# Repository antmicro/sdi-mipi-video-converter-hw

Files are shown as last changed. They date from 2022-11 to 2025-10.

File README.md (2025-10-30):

# SDI-MIPI Video Converter

Copyright (c) 2022-2025 [Antmicro](https://www.antmicro.com)


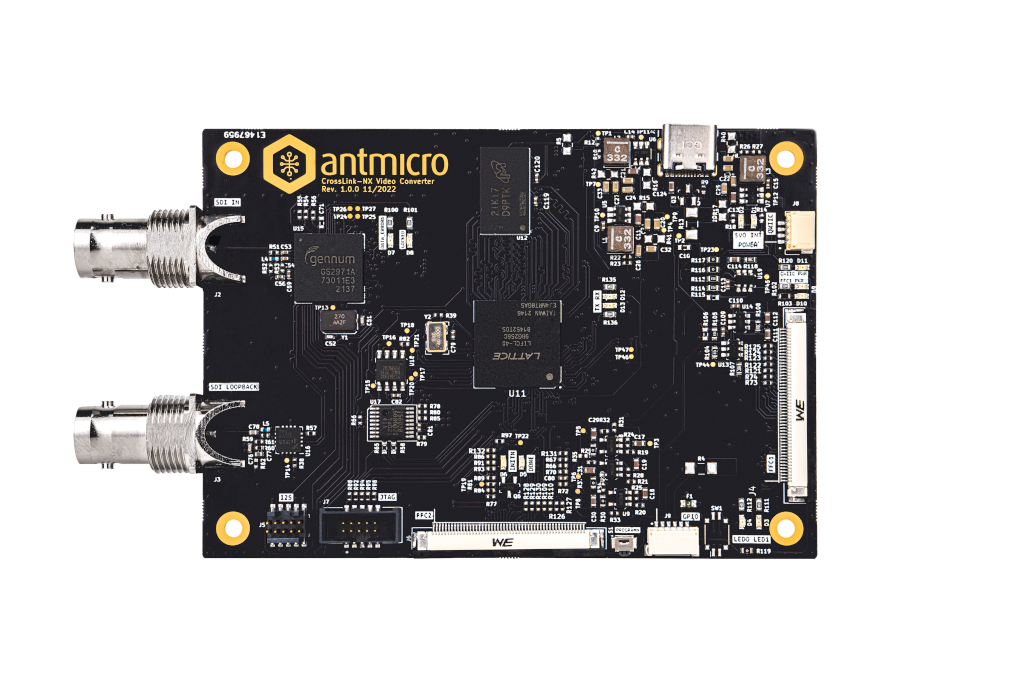
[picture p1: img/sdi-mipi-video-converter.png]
SDI-MIPI Video Converter


## Overview

This repository contains open hardware design files for a video accessory based on the [Lattice CrossLink-NX](https://www.latticesemi.com/Products/FPGAandCPLD/CrossLink-NX) FPGA which allows to connect multiple video streams from SDI or CSI inputs, process it on-board and export with CSI output.

The design files were prepared in KiCad 9.x.

## Repository structure

The main repository directory contains KiCad PCB project files, a [LICENSE](LICENSE), and a README.
The remaining files are stored in the following directories:

* `img` - contains graphics for this README

## Key Features

* LIFCL-40-9BG256C Lattice CrossLink-NX FPGA
* 3G SDI Input implemented with Semtech GS2971A deserializer 
* 3G SDI Loopback output implemented with Semtech GS2988 cable driver
* 3x4 CSI interfaces split 2/1 between two Antmicro 50-pin FFC connectors 
* 2Gbit (128Mx16) DDR3L DRAM

The board can be powered from either USB or Antmicro's 50-pin FFC connector.

Antmicro's 50-pin FFC connector is electrically compatible with several boards created by Antmicro, such as:
 
* [Jetson Nano/TX2 NX/Xavier NX Baseboard](https://github.com/antmicro/jetson-nano-baseboard)
* [OV9281 Dual Camera Board](https://github.com/antmicro/ov9281-camera-board)
* [HDMI-MIPI bridge](https://github.com/antmicro/hdmi-mipi-bridge)

## License

[Apache-2.0](LICENSE)

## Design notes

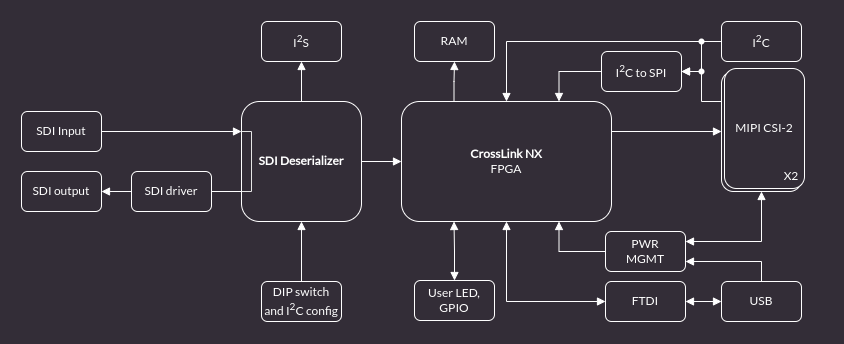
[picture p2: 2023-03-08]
doc/sdi-mipi-video-converter-diagram.png

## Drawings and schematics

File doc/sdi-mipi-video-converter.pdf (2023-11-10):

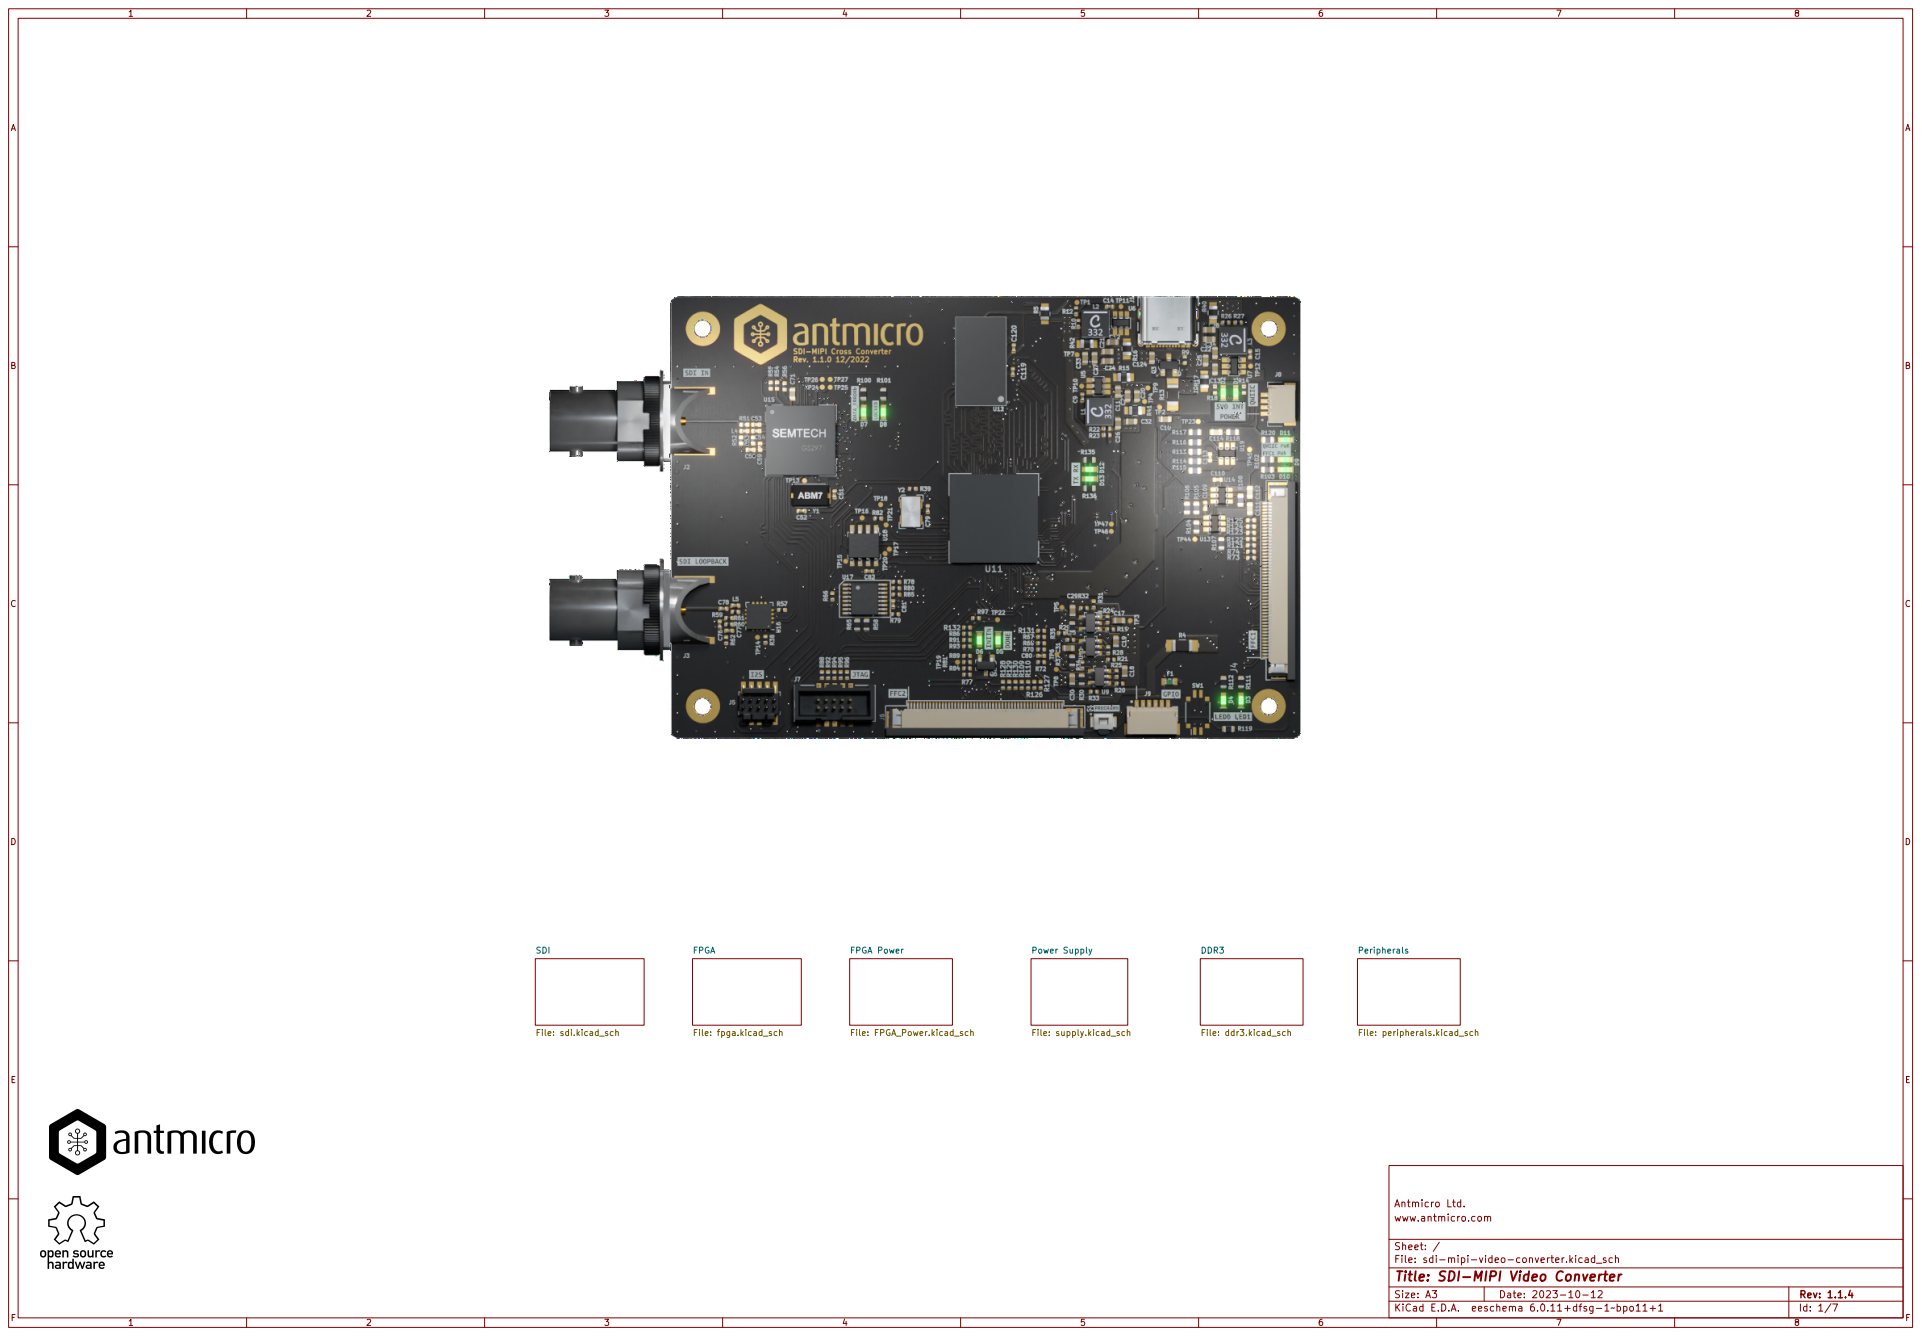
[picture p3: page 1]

Id: 1/7 Title: SDI-MIPI Video Converter File: sdi-mipi-video-converter.kicad_sch Sheet: / www.antmicro.com

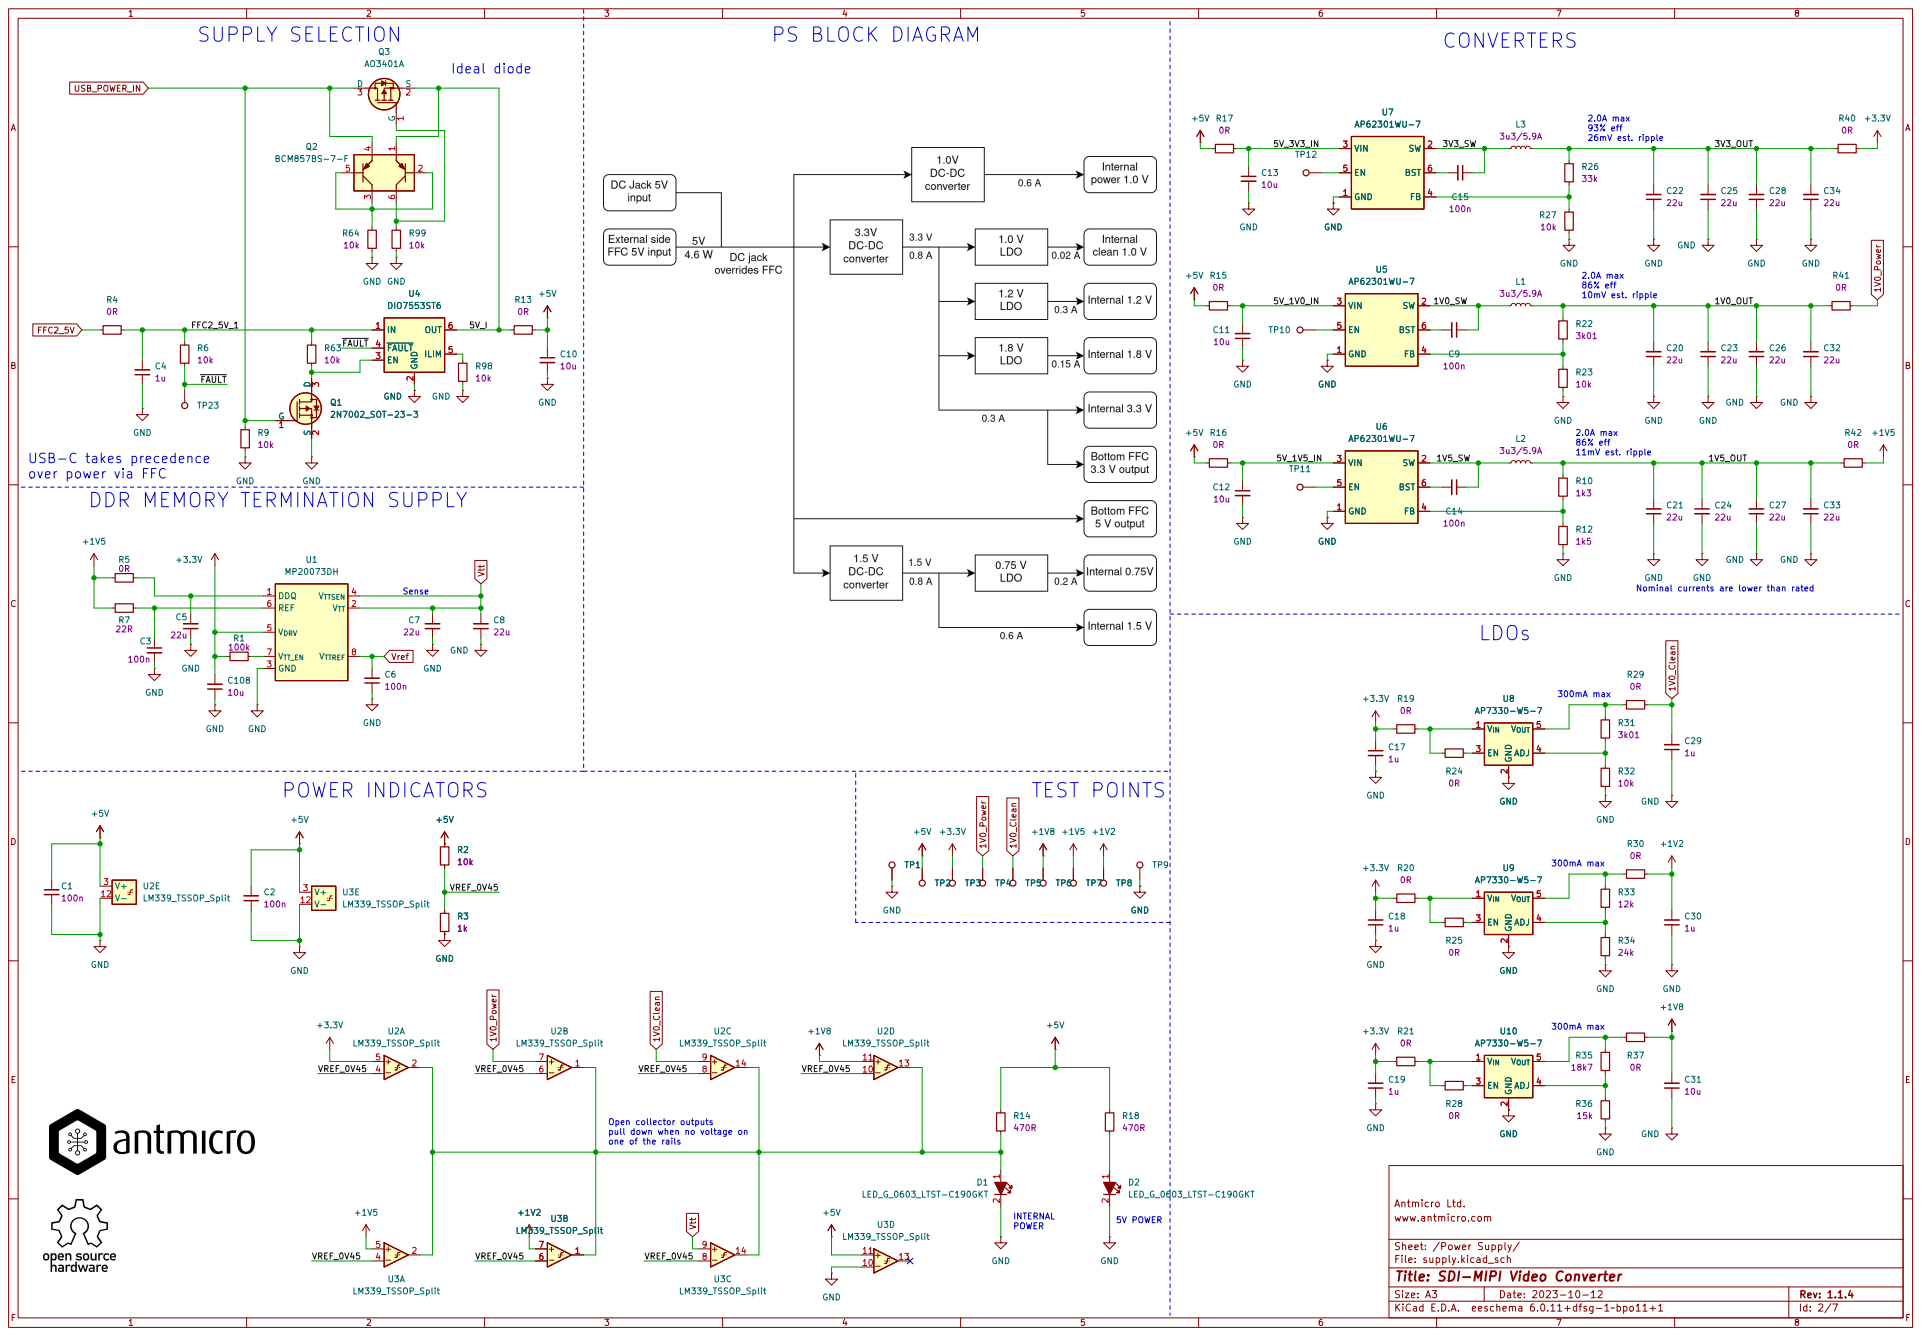
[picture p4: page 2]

2.0A max 93% eff 26mV est. ripple
+3.3V GND

2.0A max 86% eff 10mV est. ripple GND

2.0A max 86% eff 11mV est. ripple

DDR MEMORY TERMINATION SUPPLY

one of the rails

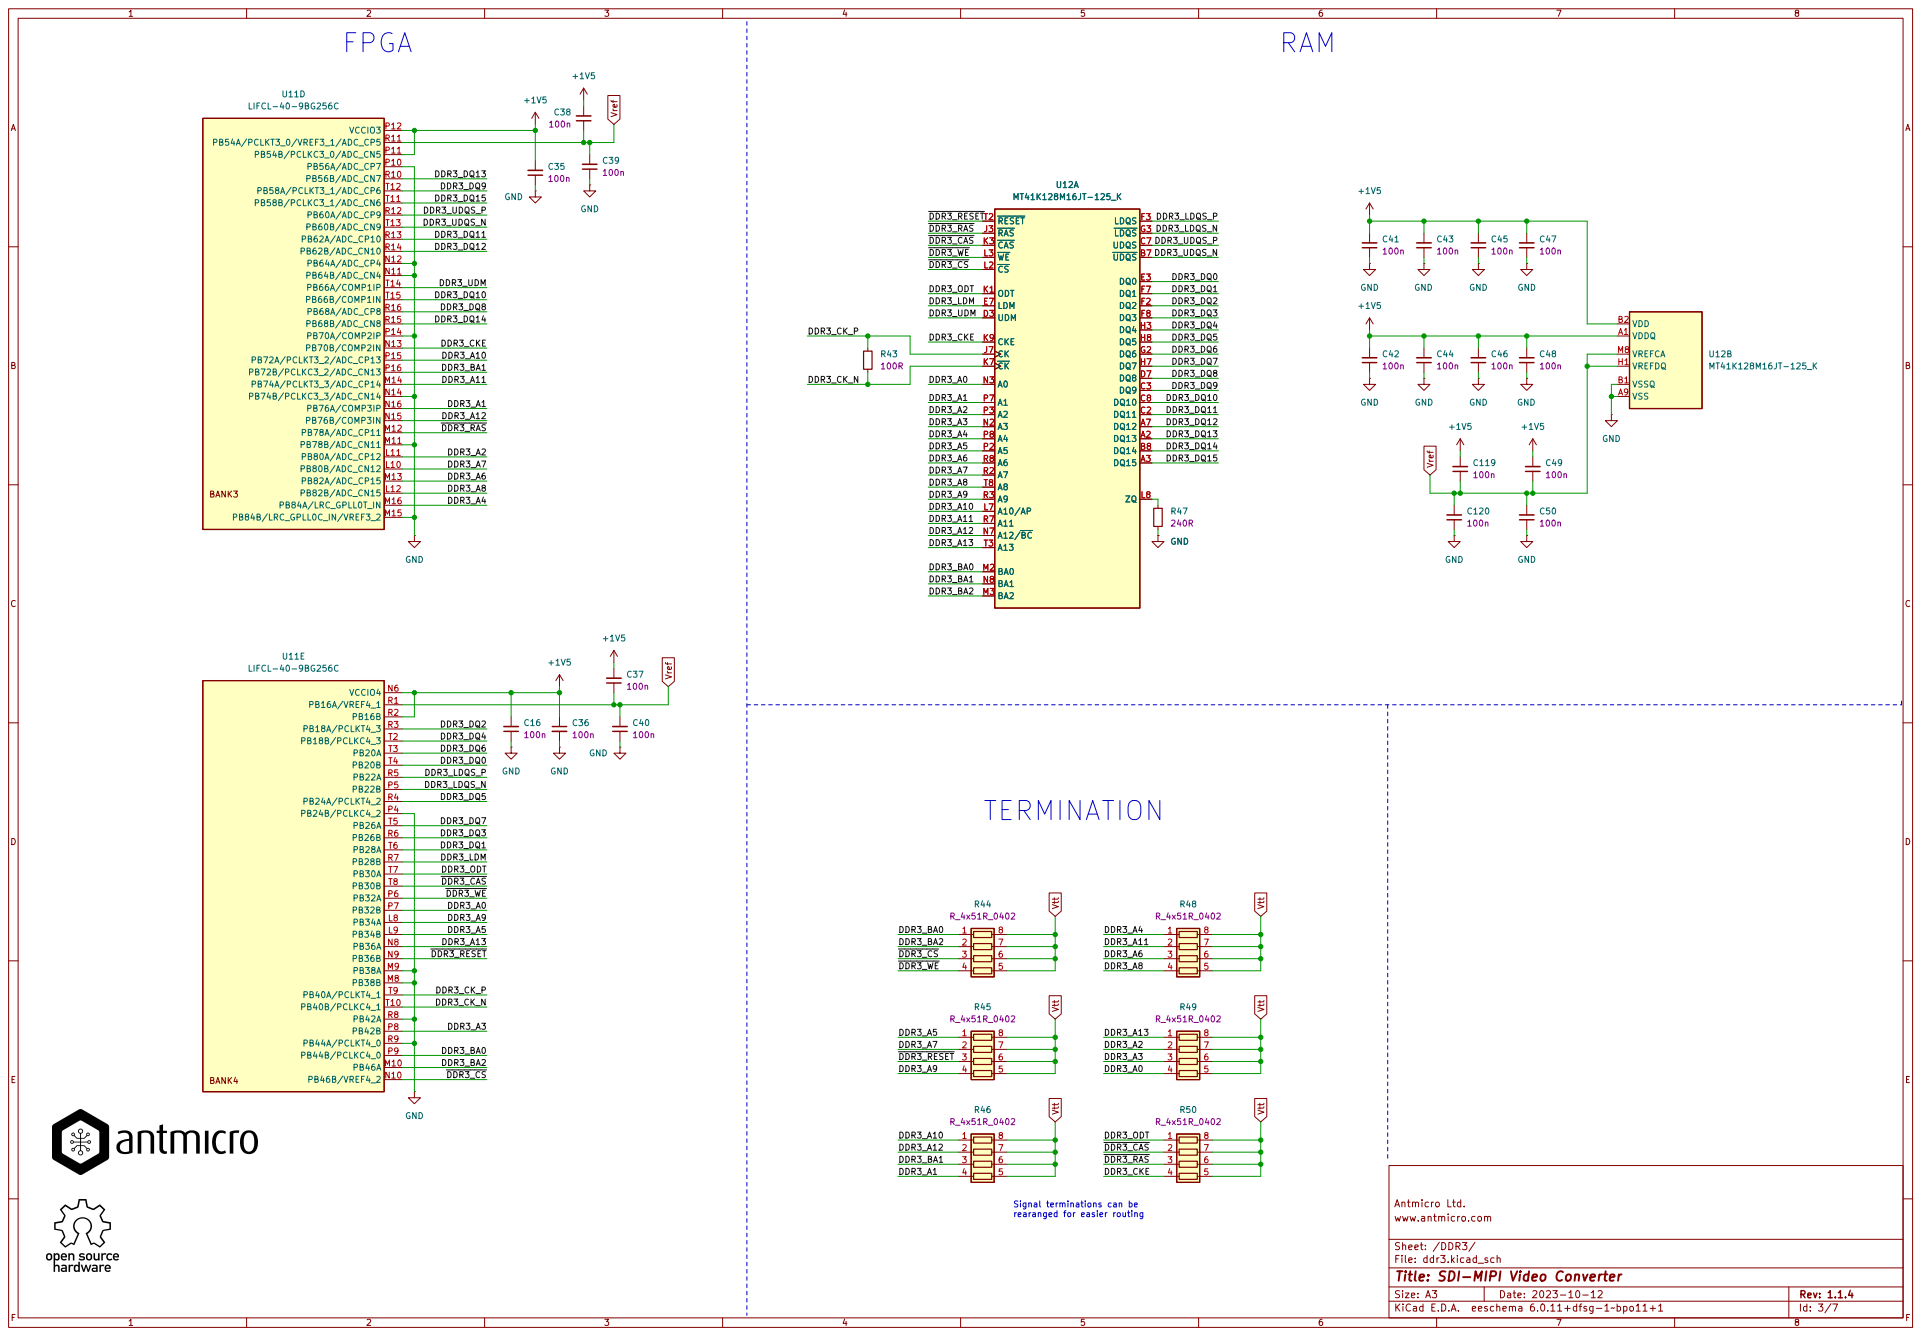
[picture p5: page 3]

Id: 3/7 Title: SDI-MIPI Video Converter File: ddr3.kicad_sch Sheet: /DDR3/ www.antmicro.com

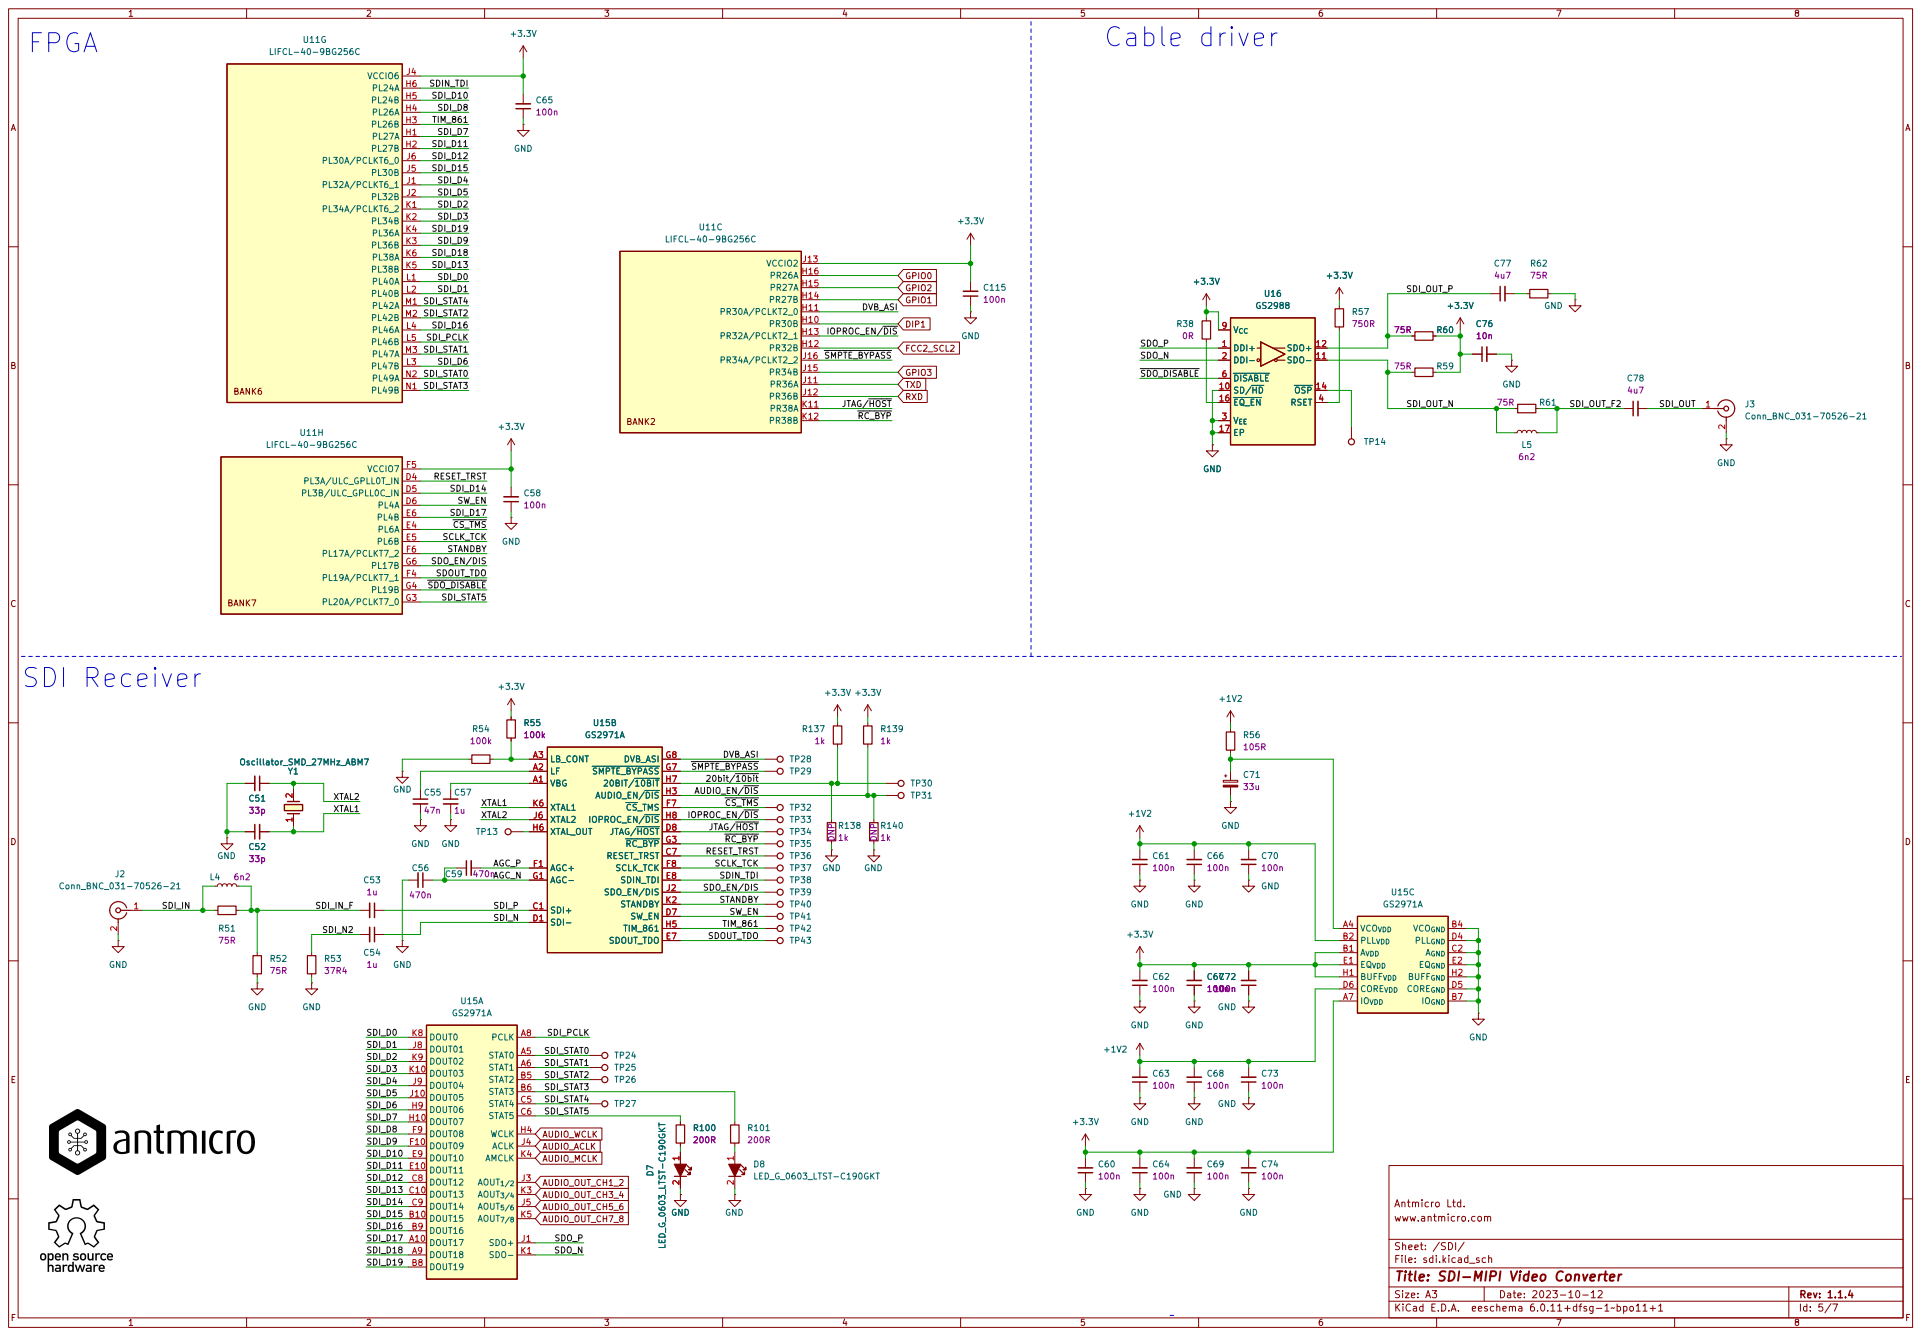
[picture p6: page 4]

Id: 5/7 Title: SDI-MIPI Video Converter File: sdi.kicad_sch Sheet: /SDI/ www.antmicro.com

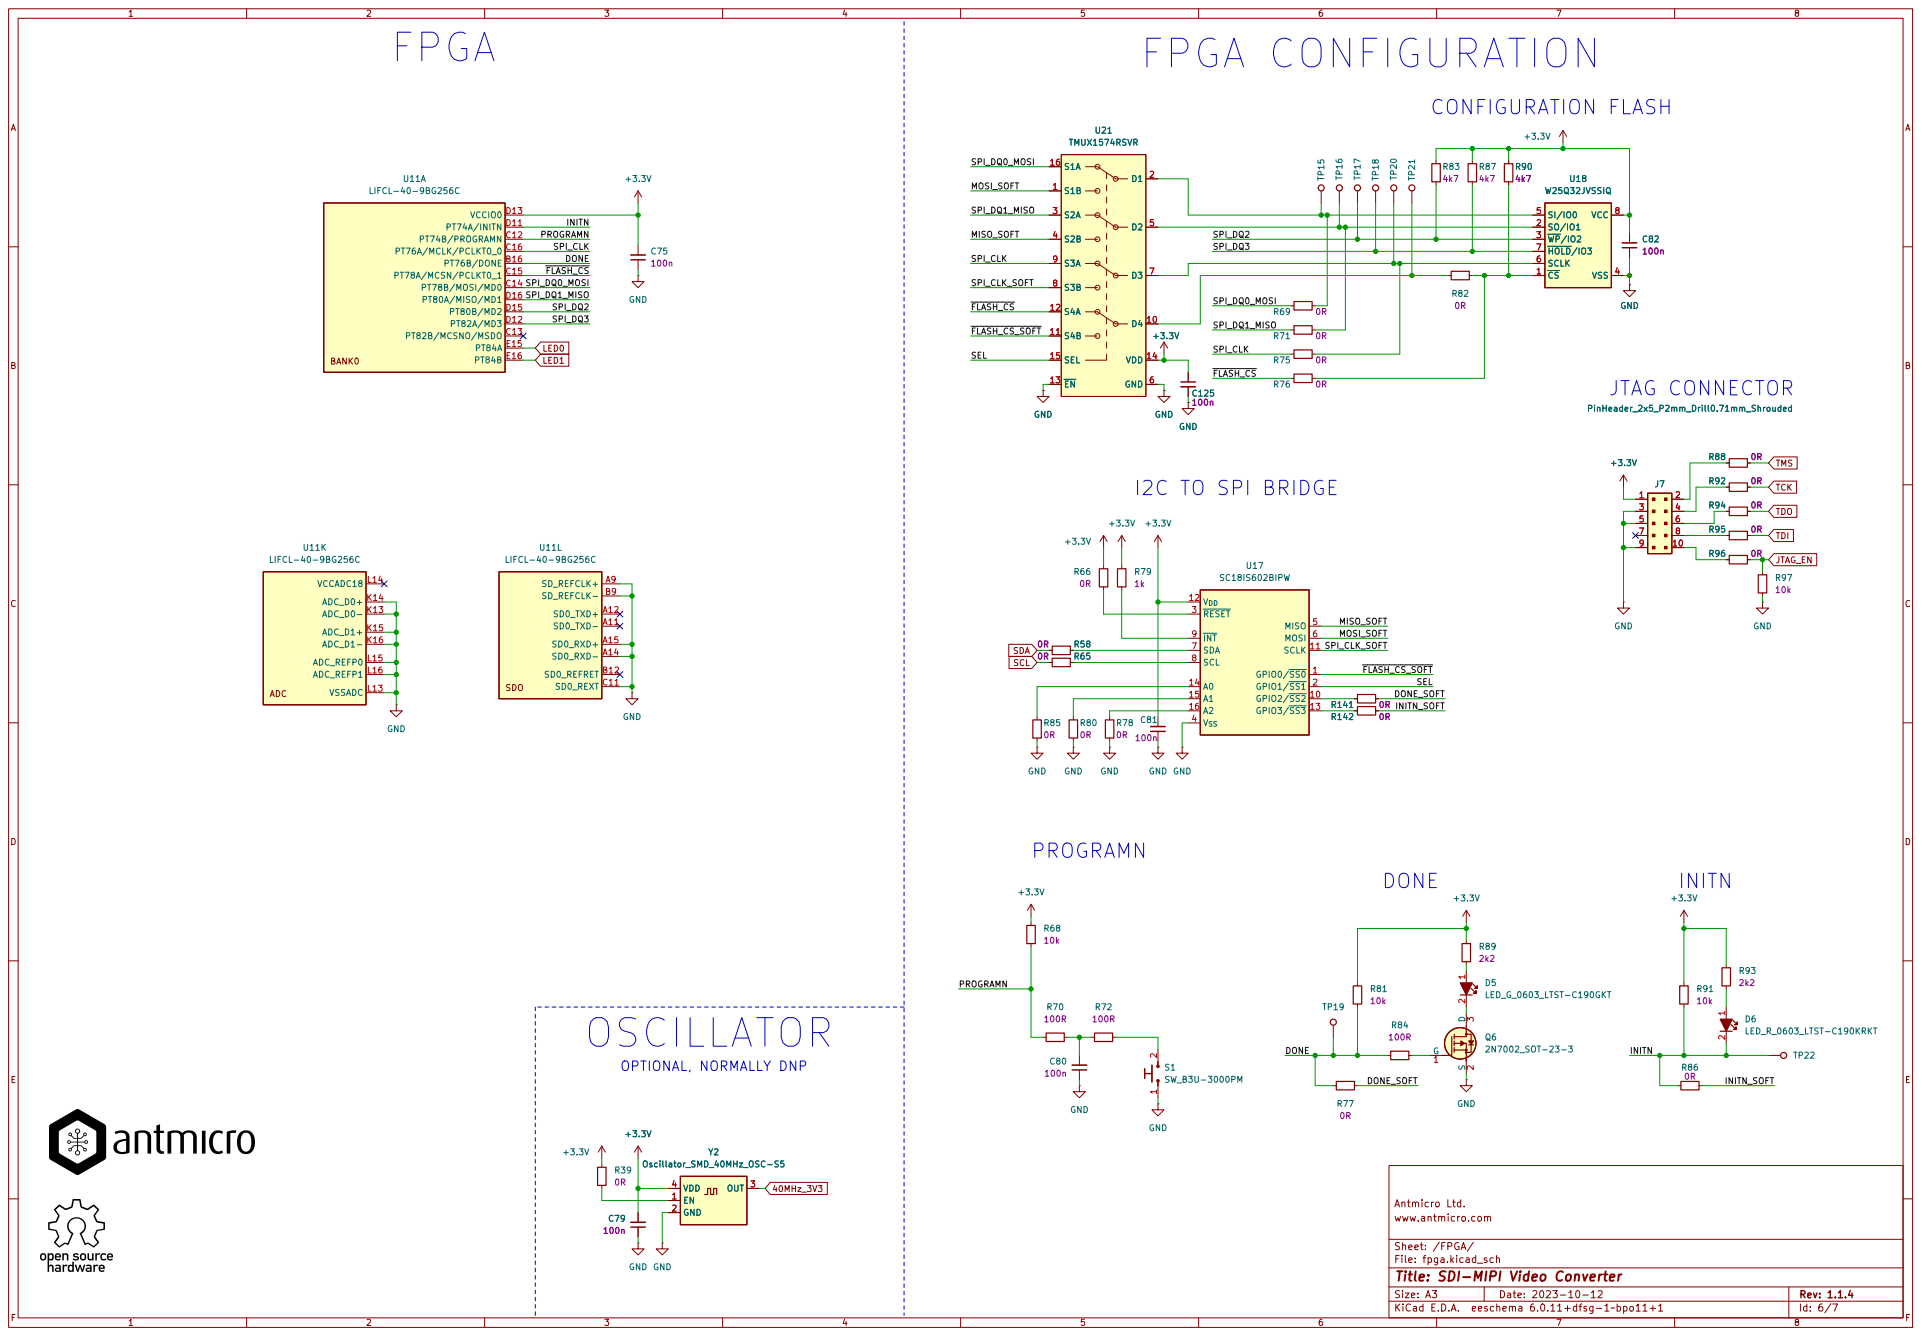
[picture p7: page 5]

Id: 6/7 Title: SDI-MIPI Video Converter File: fpga.kicad_sch Sheet: /FPGA/ www.antmicro.com

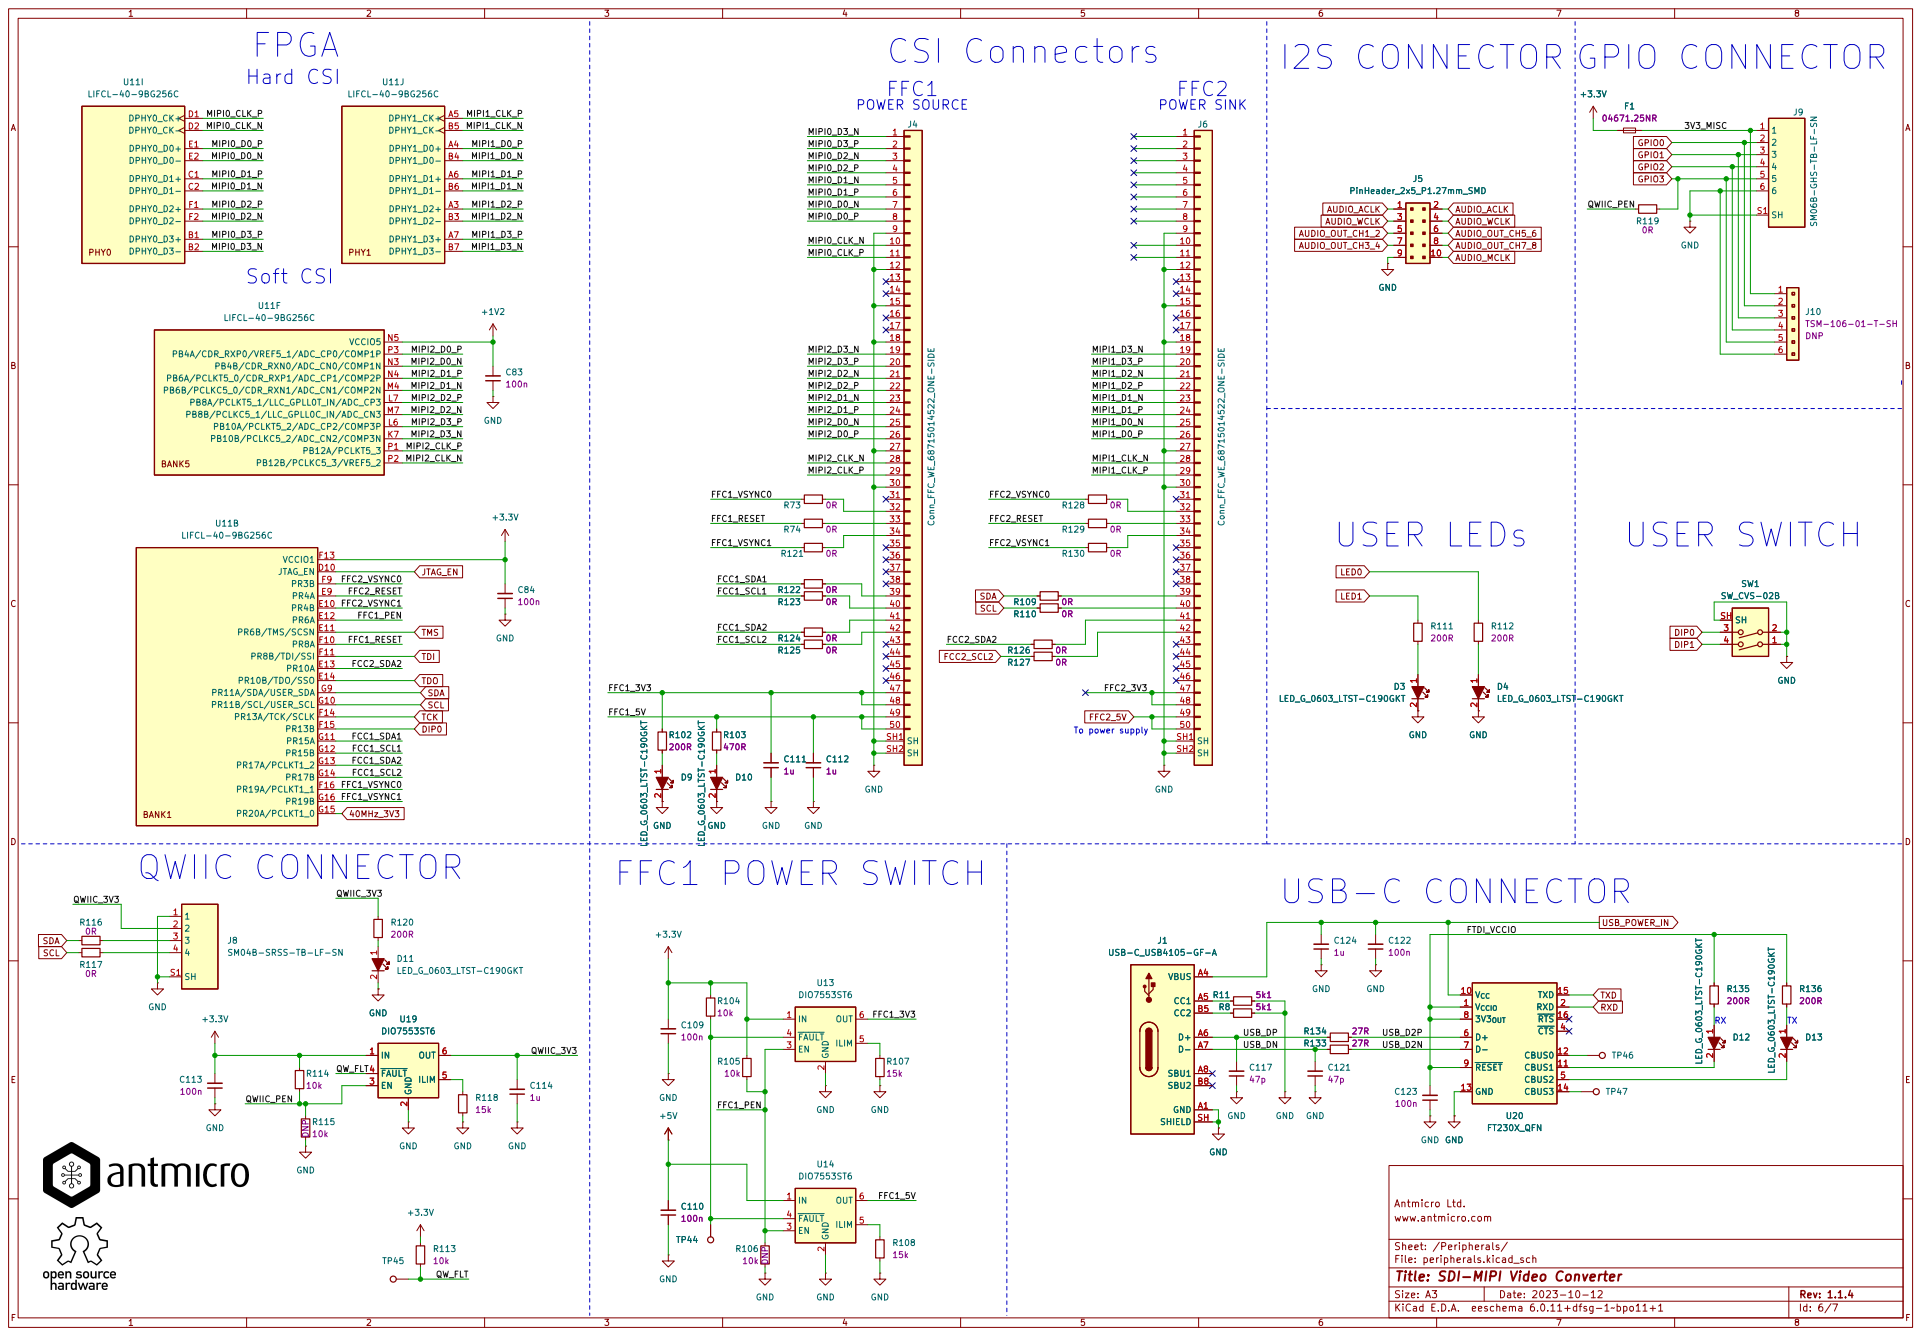
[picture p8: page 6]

J8SM04B-SRSS-TB-LF-SN

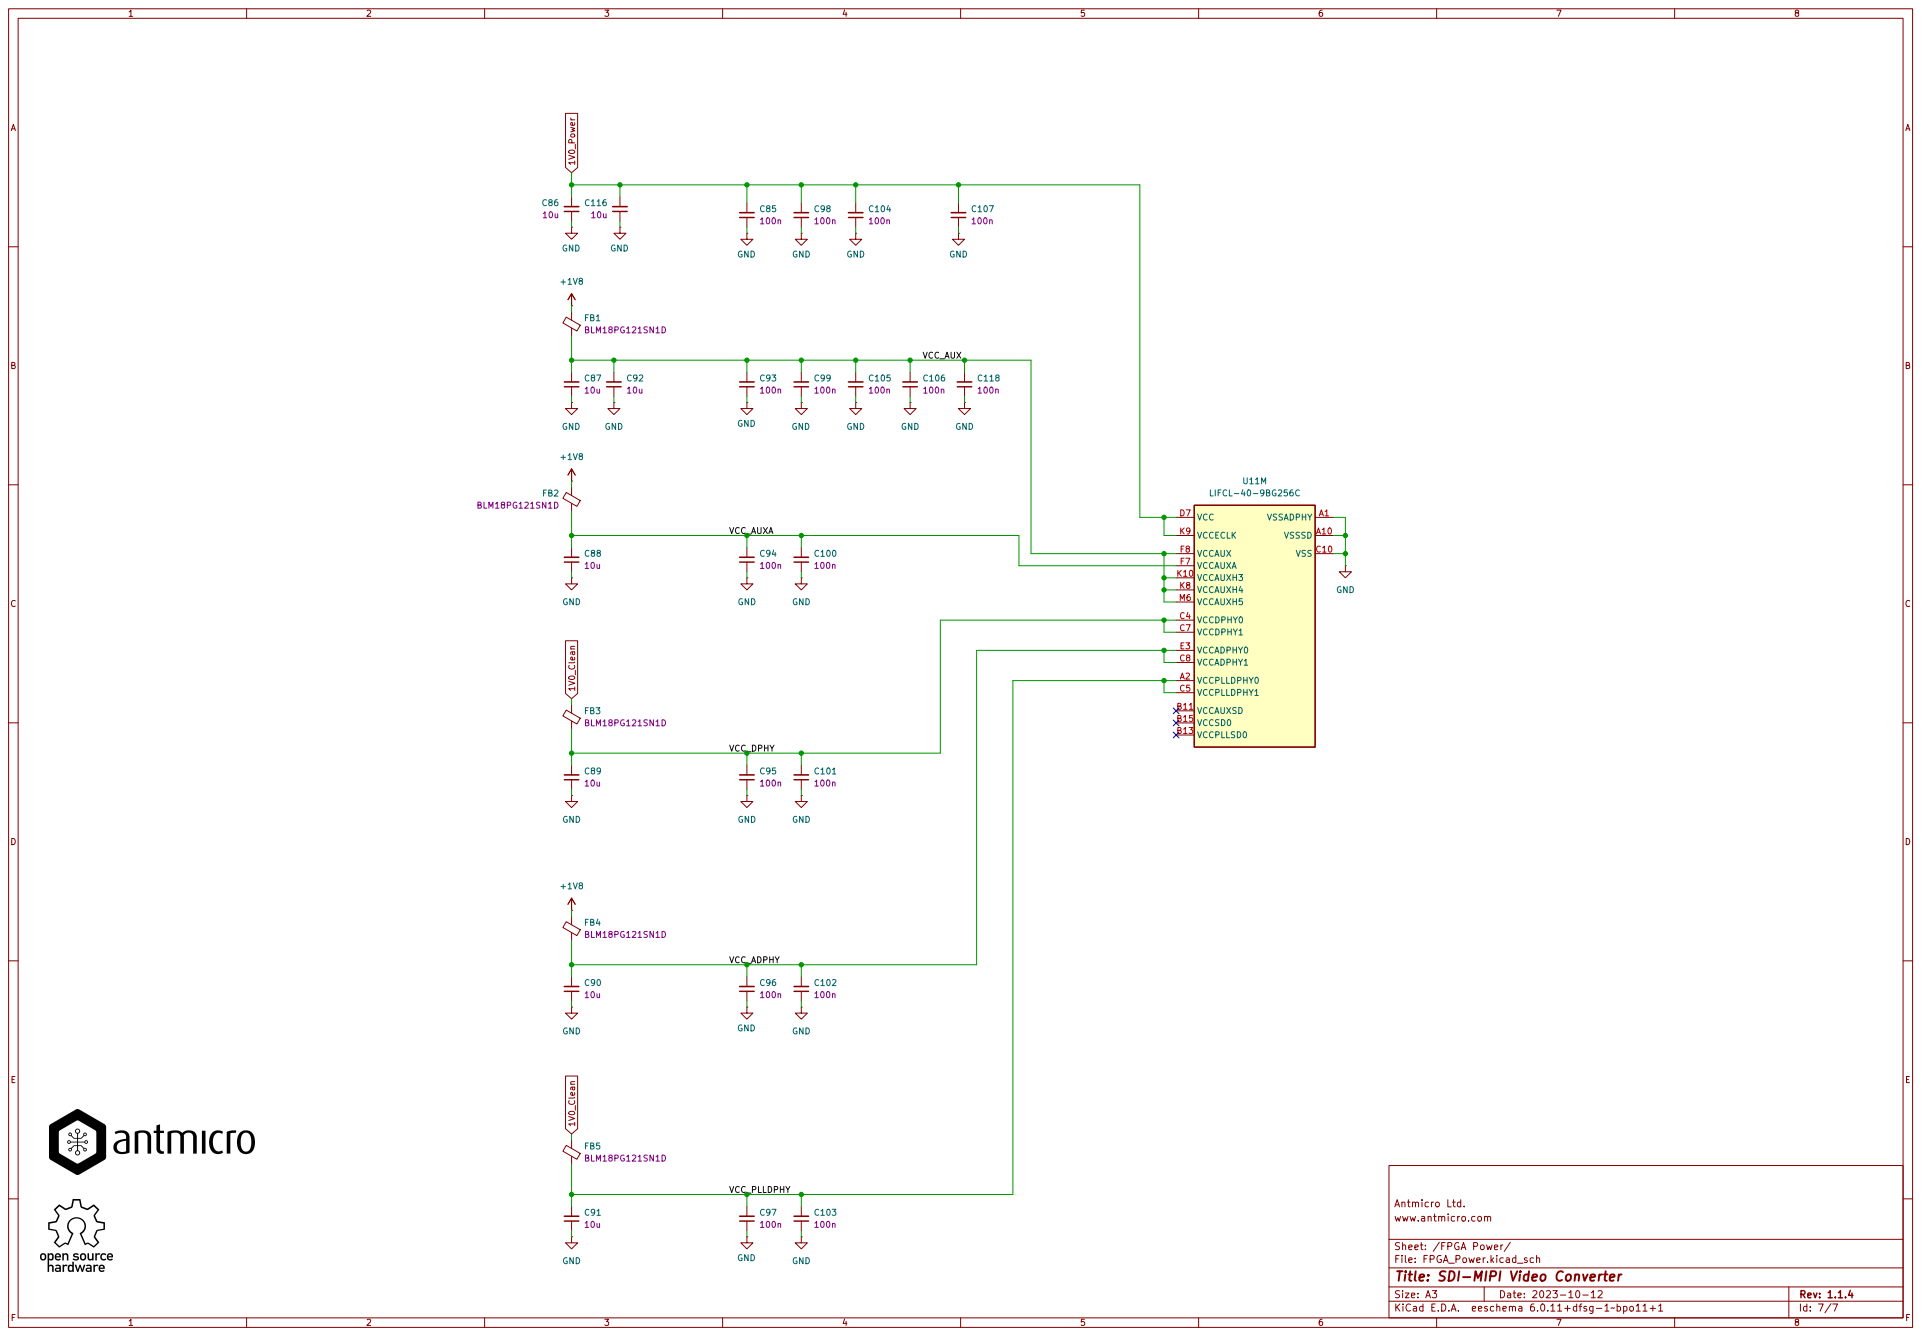
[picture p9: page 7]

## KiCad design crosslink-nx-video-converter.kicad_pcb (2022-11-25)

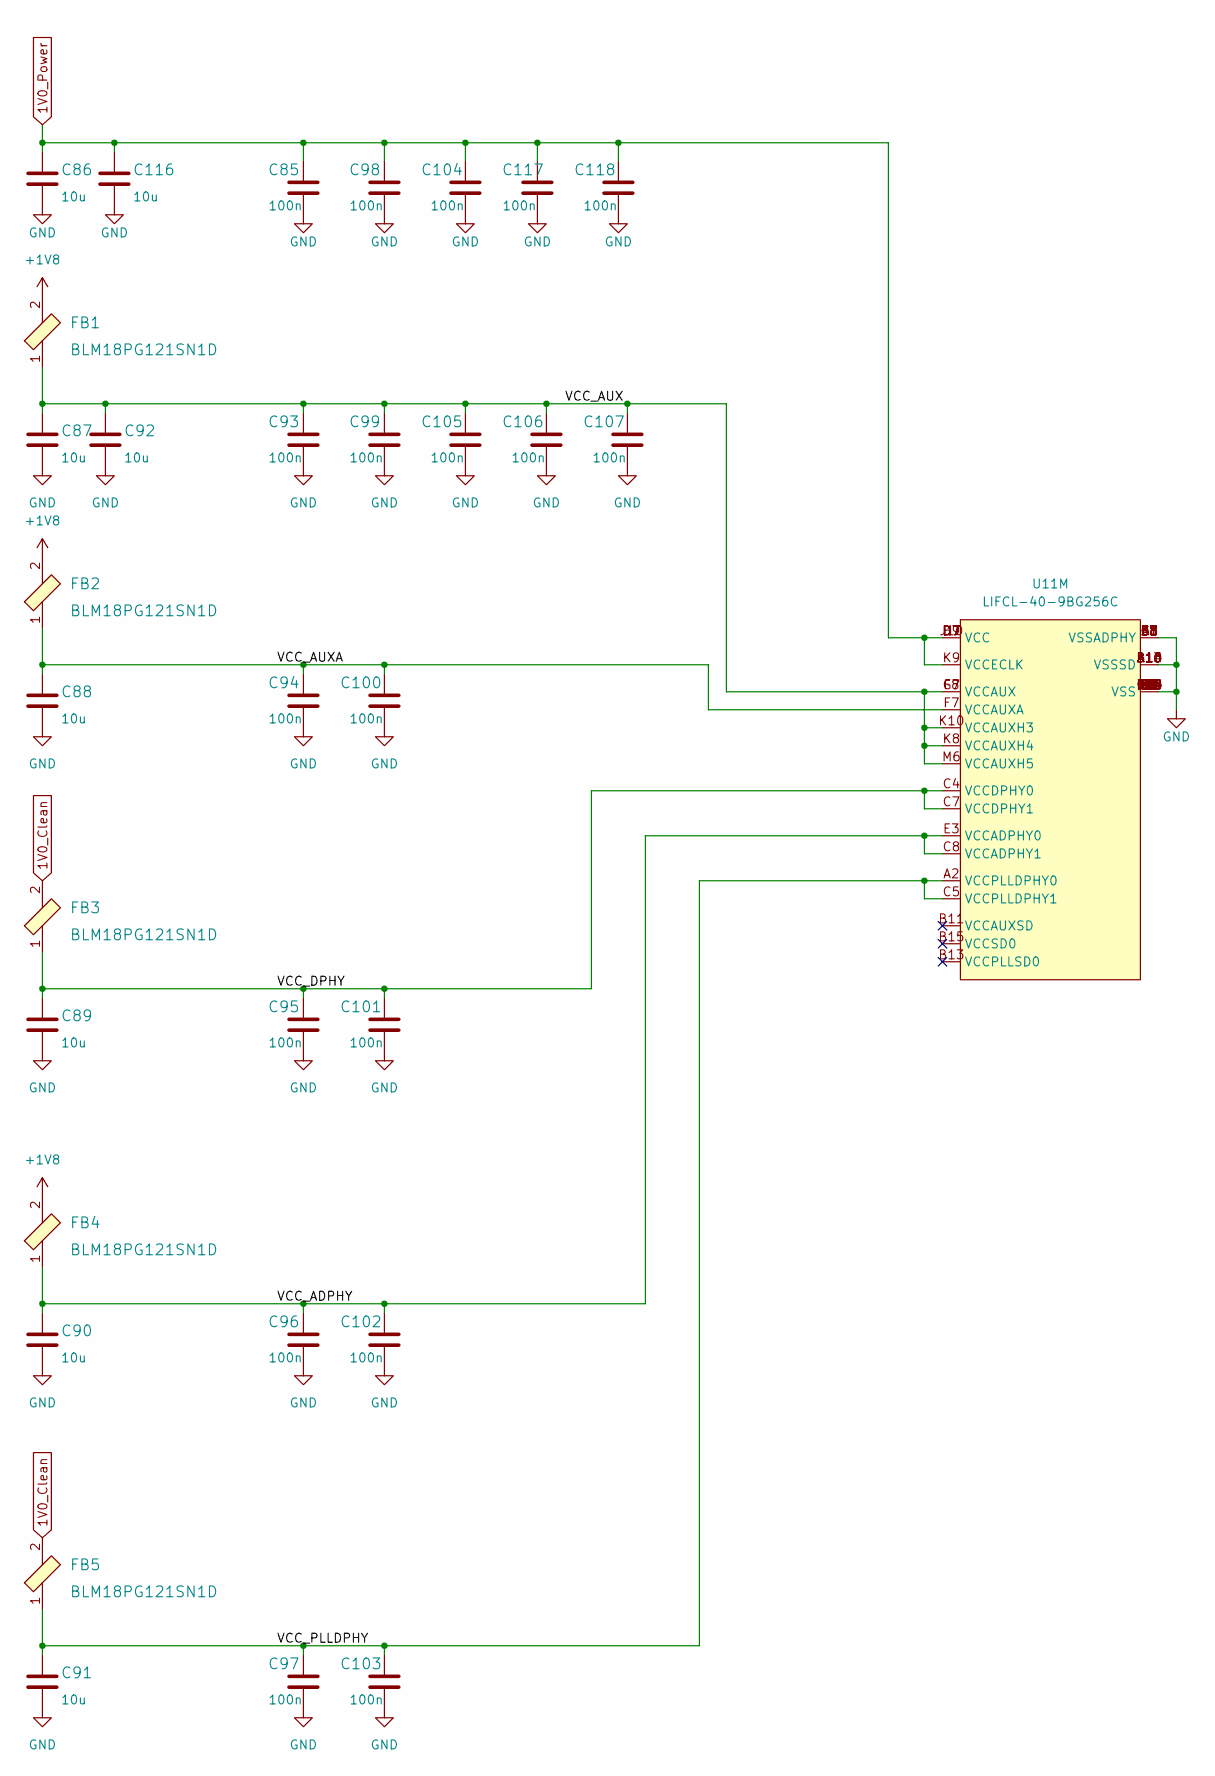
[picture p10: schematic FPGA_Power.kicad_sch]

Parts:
C85, C93, C94, C95, C96, C97, C98, C99, C100, C101, C102, C103, C104, C105, C106, C107, C117, C118: C_100n_0402; 0402-cap; MPN GRM155R61H104KE14D
C86, C87, C88, C89, C90, C91, C92, C116: C_10u_0603; 0603-cap; MPN GRM188R61A106KE69D
FB1, FB2, FB3, FB4, FB5: BLM18PG121SN1D; 0603-res; MPN BLM18PG121SN1D
U11: LIFCL-40-9BG256C; BGA-256_16x16_14.0x14.0mm; MPN LIFCL-40-9BG256C

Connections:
/FPGA Power/VCC_ADPHY: C90.1, C96.1, C102.1, FB4.1, U11.C8 (VCCADPHY1), U11.E3 (VCCADPHY0)
/FPGA Power/VCC_AUX: C87.1, C92.1, C93.1, C99.1, C105.1, C106.1, C107.1, FB1.1, U11.F8 (VCCAUX), U11.G7 (VCCAUX), U11.K8 (VCCAUXH4), U11.K10 (VCCAUXH3), U11.M6 (VCCAUXH5)
/FPGA Power/VCC_AUXA: C88.1, C94.1, C100.1, FB2.1, U11.F7 (VCCAUXA)
/FPGA Power/VCC_DPHY: C89.1, C95.1, C101.1, FB3.1, U11.C4 (VCCDPHY0), U11.C7 (VCCDPHY1)
/FPGA Power/VCC_PLLDPHY: C91.1, C97.1, C103.1, FB5.1, U11.A2 (VCCPLLDPHY0), U11.C5 (VCCPLLDPHY1)

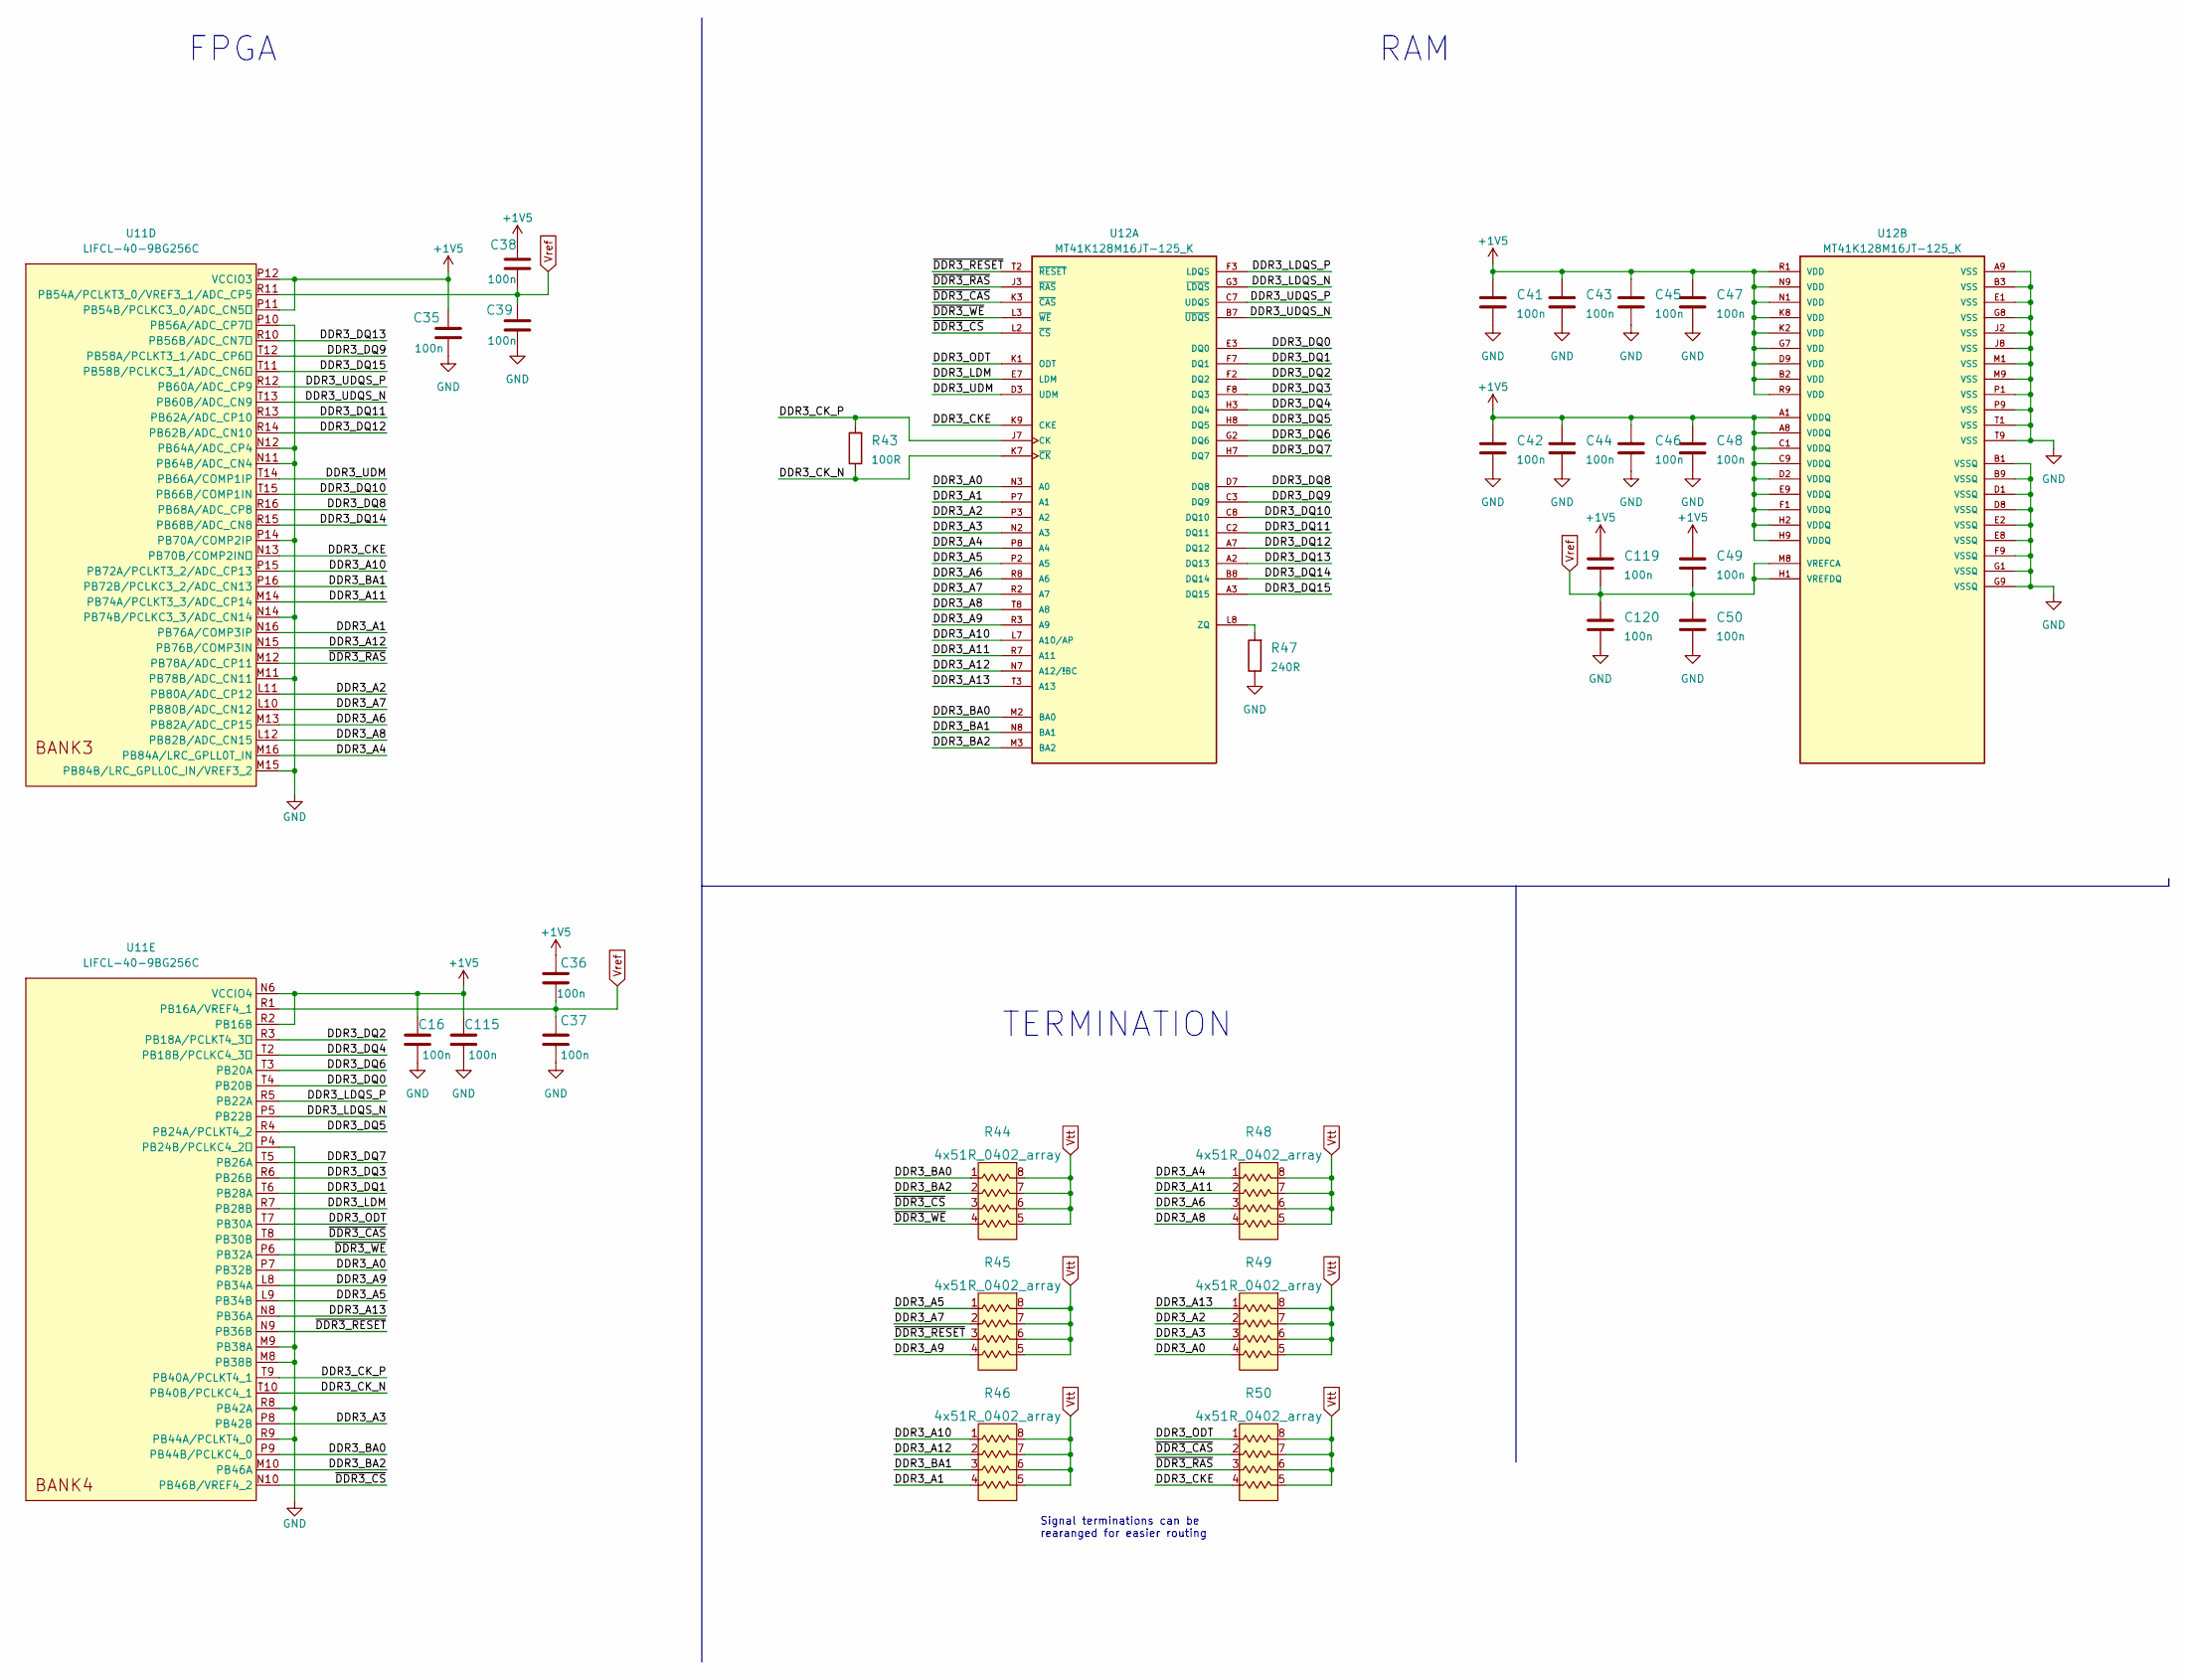
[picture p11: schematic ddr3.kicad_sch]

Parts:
C16, C35, C36, C37, C38, C39, C41, C42, C43, C44, C45, C46, C47, C48, C49, C50, C115, C119, C120: C_100n_0402; 0402-cap; MPN GRM155R61H104KE14D
R43: R_100R_0201; 0201-res; MPN CR0201AFW-1000GAS
R44, R45, R46, R48, R49, R50: 4x51R_0402_array; R_Array_4x0402; MPN EXB28V510JX
R47: R_240R_1%_0402; 0402-res; MPN RC0402FR-13240RL
U11: LIFCL-40-9BG256C; BGA-256_16x16_14.0x14.0mm; MPN LIFCL-40-9BG256C
U12: MT41K128M16JT-125_K; BGA80P96C6X16_800X1400X110; MPN MT41K128M16JT-125:K

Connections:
+1V5: C16.1, C35.1, C36.1, C38.1, C41.1, C42.1, C43.1, C44.1, C45.1, C46.1, C47.1, C48.1, C49.1, C115.1, C119.1, U11.N6 (VCCIO4), U11.P11 (PB54B/PCLKC3_0/ADC_CN5), U11.P12 (VCCIO3), U11.R2 (PB16B), U12.A1 (VDDQ), U12.A8 (VDDQ), U12.B2 (VDD), U12.C1 (VDDQ), U12.C9 (VDDQ), U12.D2 (VDDQ), U12.D9 (VDD), U12.E9 (VDDQ), U12.F1 (VDDQ), U12.G7 (VDD), U12.H2 (VDDQ), U12.H9 (VDDQ), U12.K2 (VDD), U12.K8 (VDD), U12.N1 (VDD), U12.N9 (VDD), U12.R1 (VDD), U12.R9 (VDD); also elsewhere on the board
/DDR3/DDR3_A0: R49.4, U11.P7 (PB32B), U12.N3 (A0)
/DDR3/DDR3_A1: R46.4, U11.N16 (PB76A/COMP3IP), U12.P7 (A1)
/DDR3/DDR3_A2: R49.2, U11.L11 (PB80A/ADC_CP12), U12.P3 (A2)
/DDR3/DDR3_A3: R49.3, U11.P8 (PB42B), U12.N2 (A3)
/DDR3/DDR3_A4: R48.1, U11.M16 (PB84A/LRC_GPLL0T_IN), U12.P8 (A4)
/DDR3/DDR3_A5: R45.1, U11.L9 (PB34B), U12.P2 (A5)
/DDR3/DDR3_A6: R48.3, U11.M13 (PB82A/ADC_CP15), U12.R8 (A6)
/DDR3/DDR3_A7: R45.2, U11.L10 (PB80B/ADC_CN12), U12.R2 (A7)
/DDR3/DDR3_A8: R48.4, U11.L12 (PB82B/ADC_CN15), U12.T8 (A8)
/DDR3/DDR3_A9: R45.4, U11.L8 (PB34A), U12.R3 (A9)
/DDR3/DDR3_A10: R46.1, U11.P15 (PB72A/PCLKT3_2/ADC_CP13), U12.L7 (A10/AP)
/DDR3/DDR3_A11: R48.2, U11.M14 (PB74A/PCLKT3_3/ADC_CP14), U12.R7 (A11)
/DDR3/DDR3_A12: R46.2, U11.N15 (PB76B/COMP3IN), U12.N7 (A12/!BC)
/DDR3/DDR3_A13: R49.1, U11.N8 (PB36A), U12.T3 (A13)
/DDR3/DDR3_BA0: R44.1, U11.P9 (PB44B/PCLKC4_0), U12.M2 (BA0)
/DDR3/DDR3_BA1: R46.3, U11.P16 (PB72B/PCLKC3_2/ADC_CN13), U12.N8 (BA1)
/DDR3/DDR3_BA2: R44.2, U11.M10 (PB46A), U12.M3 (BA2)
/DDR3/DDR3_CKE: R50.4, U11.N13 (PB70B/COMP2IN), U12.K9 (CKE)
/DDR3/DDR3_CK_N: R43.1, U11.T10 (PB40B/PCLKC4_1), U12.K7 (~CK)
/DDR3/DDR3_CK_P: R43.2, U11.T9 (PB40A/PCLKT4_1), U12.J7 (CK)
/DDR3/DDR3_DQ0: U11.T4 (PB20B), U12.E3 (DQ0)
/DDR3/DDR3_DQ1: U11.T6 (PB28A), U12.F7 (DQ1)
/DDR3/DDR3_DQ2: U11.R3 (PB18A/PCLKT4_3), U12.F2 (DQ2)
/DDR3/DDR3_DQ3: U11.R6 (PB26B), U12.F8 (DQ3)
/DDR3/DDR3_DQ4: U11.T2 (PB18B/PCLKC4_3), U12.H3 (DQ4)
/DDR3/DDR3_DQ5: U11.R4 (PB24A/PCLKT4_2), U12.H8 (DQ5)
/DDR3/DDR3_DQ6: U11.T3 (PB20A), U12.G2 (DQ6)
/DDR3/DDR3_DQ7: U11.T5 (PB26A), U12.H7 (DQ7)
/DDR3/DDR3_DQ8: U11.R16 (PB68A/ADC_CP8), U12.D7 (DQ8)
/DDR3/DDR3_DQ9: U11.T12 (PB58A/PCLKT3_1/ADC_CP6), U12.C3 (DQ9)
/DDR3/DDR3_DQ10: U11.T15 (PB66B/COMP1IN), U12.C8 (DQ10)
/DDR3/DDR3_DQ11: U11.R13 (PB62A/ADC_CP10), U12.C2 (DQ11)
/DDR3/DDR3_DQ12: U11.R14 (PB62B/ADC_CN10), U12.A7 (DQ12)
/DDR3/DDR3_DQ13: U11.R10 (PB56B/ADC_CN7), U12.A2 (DQ13)
/DDR3/DDR3_DQ14: U11.R15 (PB68B/ADC_CN8), U12.B8 (DQ14)
/DDR3/DDR3_DQ15: U11.T11 (PB58B/PCLKC3_1/ADC_CN6), U12.A3 (DQ15)
/DDR3/DDR3_LDM: U11.R7 (PB28B), U12.E7 (LDM)
/DDR3/DDR3_LDQS_N: U11.P5 (PB22B), U12.G3 (~LDQS)
/DDR3/DDR3_LDQS_P: U11.R5 (PB22A), U12.F3 (LDQS)
/DDR3/DDR3_ODT: R50.1, U11.T7 (PB30A), U12.K1 (ODT)
/DDR3/DDR3_UDM: U11.T14 (PB66A/COMP1IP), U12.D3 (UDM)
/DDR3/DDR3_UDQS_N: U11.T13 (PB60B/ADC_CN9), U12.B7 (~UDQS)
/DDR3/DDR3_UDQS_P: U11.R12 (PB60A/ADC_CP9), U12.C7 (UDQS)
/DDR3/~DDR3_CAS: R50.2, U11.T8 (PB30B), U12.K3 (~CAS)
/DDR3/~DDR3_CS: R44.3, U11.N10 (PB46B/VREF4_2), U12.L2 (~CS)
/DDR3/~DDR3_RAS: R50.3, U11.M12 (PB78A/ADC_CP11), U12.J3 (~RAS)
/DDR3/~DDR3_RESET: R45.3, U11.N9 (PB36B), U12.T2 (~RESET)
/DDR3/~DDR3_WE: R44.4, U11.P6 (PB32A), U12.L3 (~WE)
unnamed: R47.2, U12.L8 (ZQ)
Vref: C36.2, C37.1, C38.2, C39.1, C49.2, C50.1, C119.2, C120.1, U11.R1 (PB16A/VREF4_1), U11.R11 (PB54A/PCLKT3_0/VREF3_1/ADC_CP5), U12.H1 (VREFDQ), U12.M8 (VREFCA); also elsewhere on the board
Vtt: R44.5, R44.6, R44.7, R44.8, R45.5, R45.6, R45.7, R45.8, R46.5, R46.6, R46.7, R46.8, R48.5, R48.6, R48.7, R48.8, R49.5, R49.6, R49.7, R49.8, R50.5, R50.6, R50.7, R50.8; also elsewhere on the board

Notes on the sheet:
FPGA
TERMINATION
RAM
Signal terminations can be rearanged for easier routing

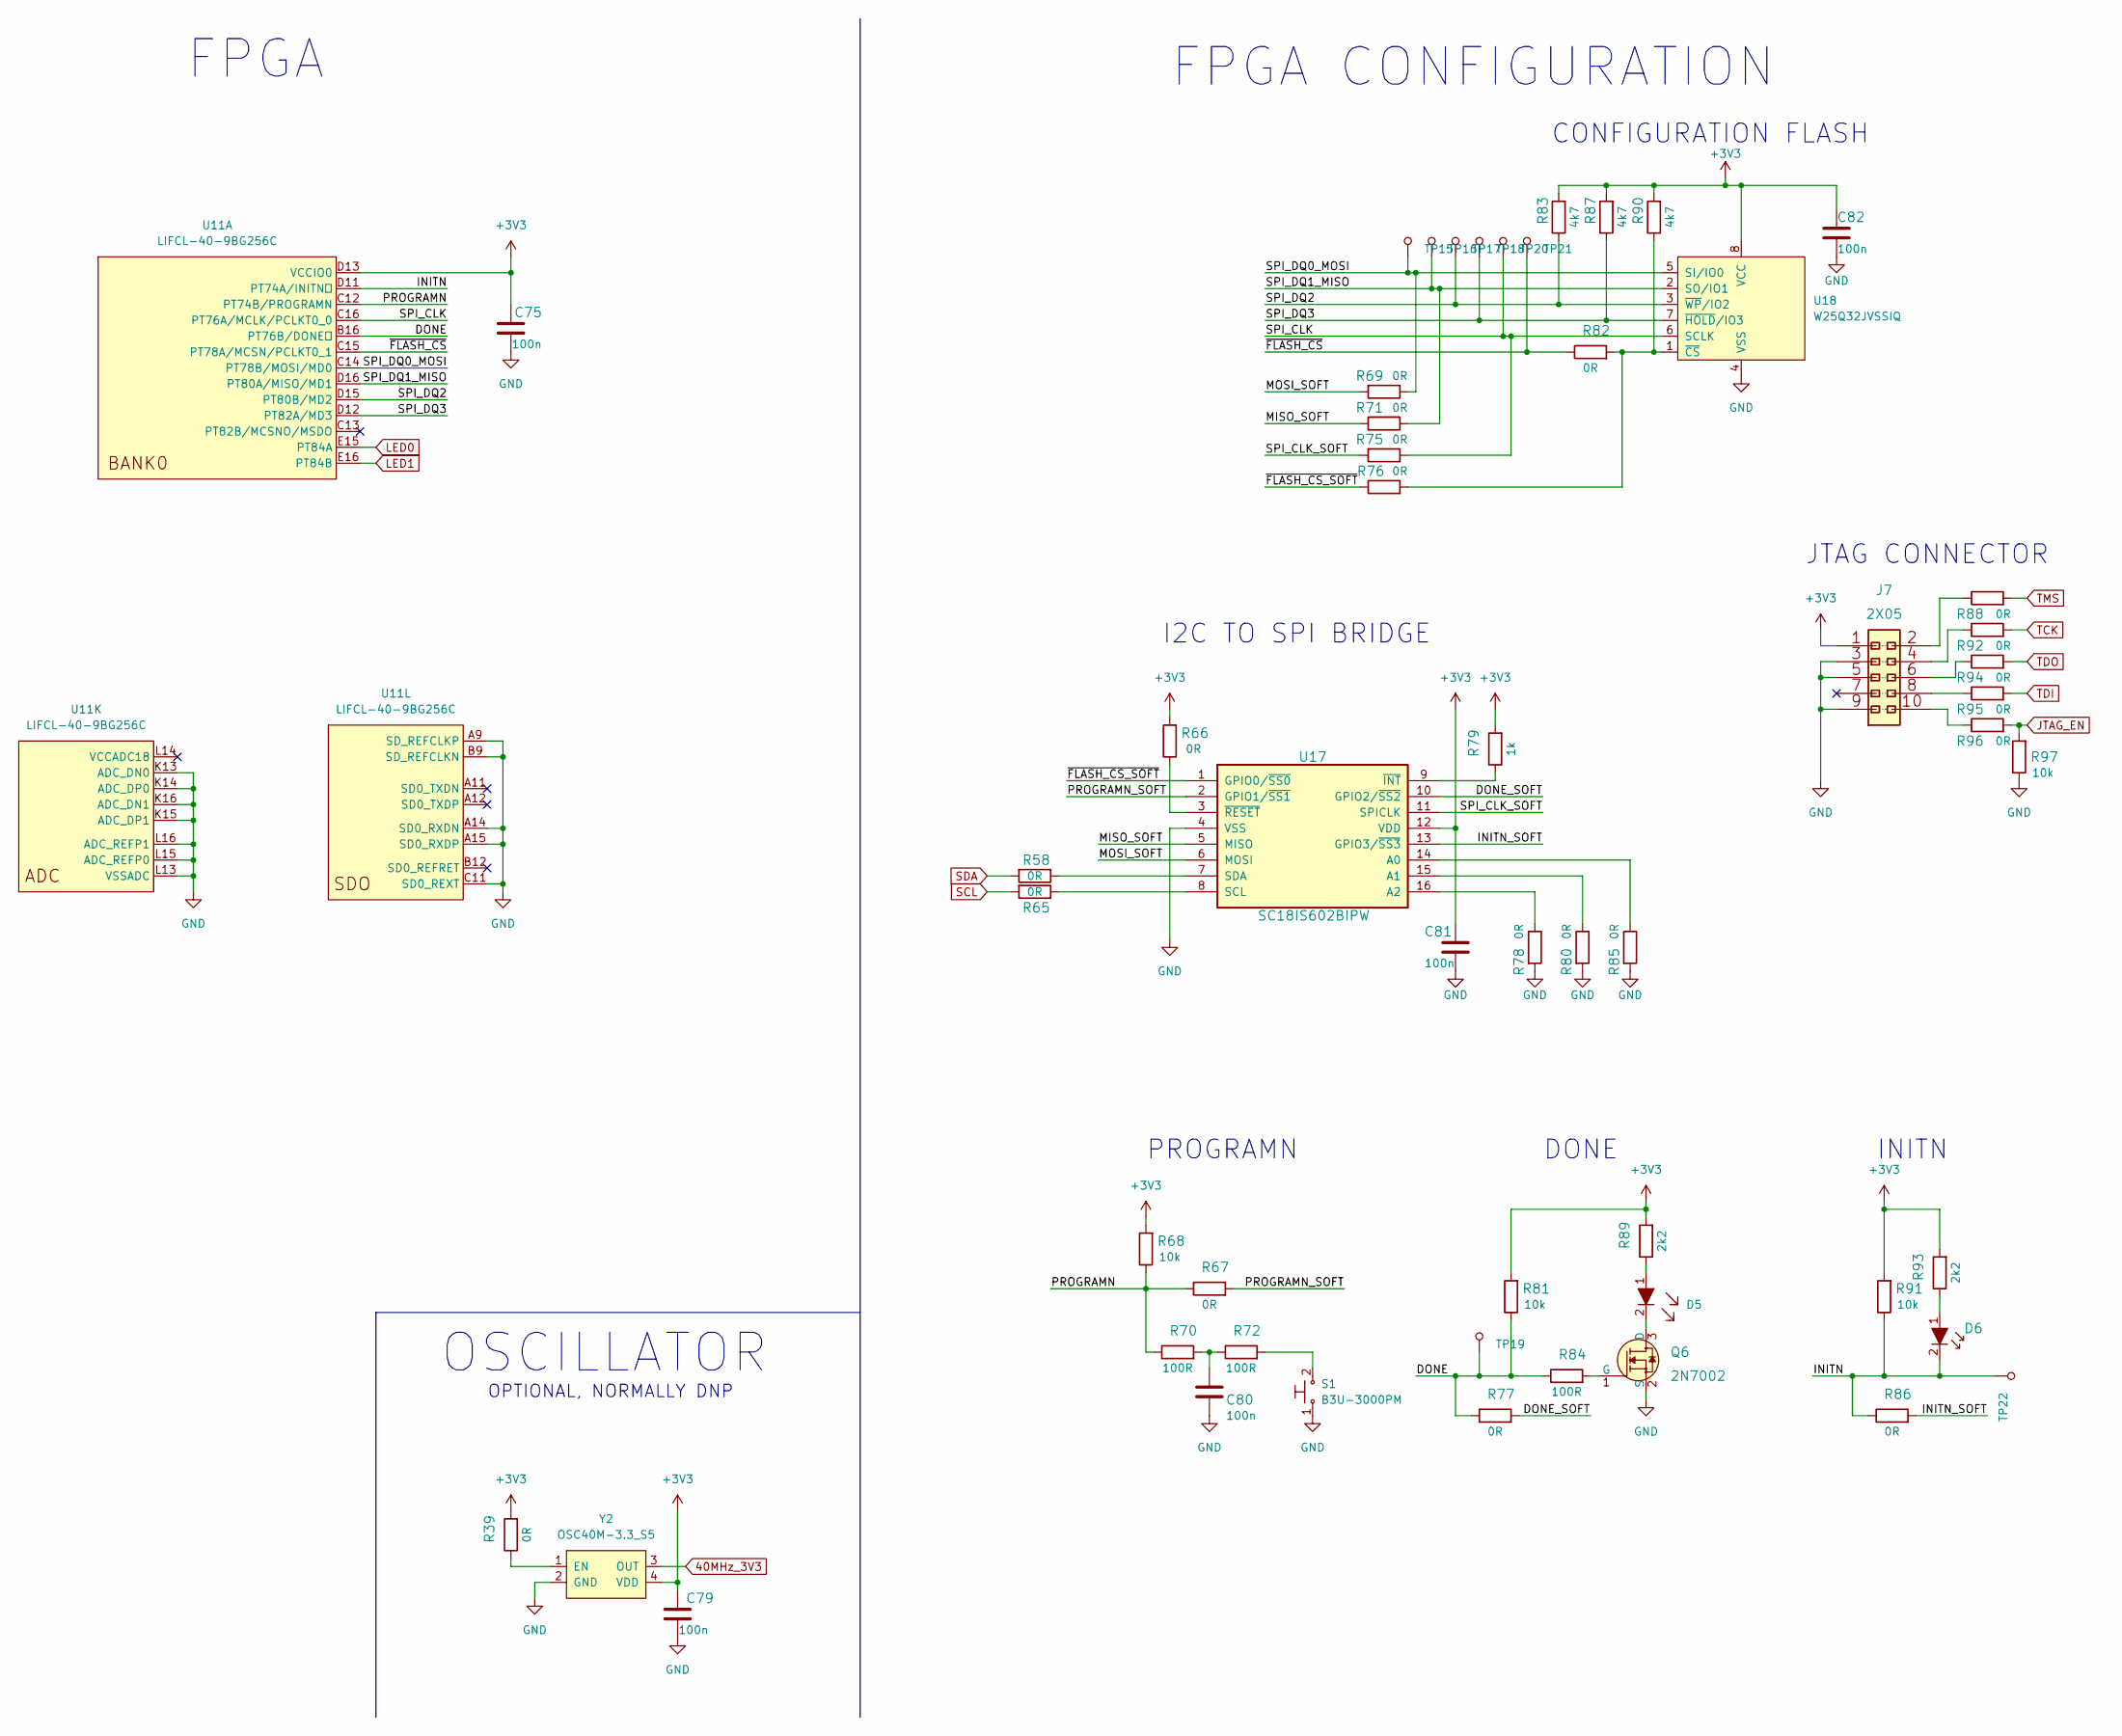
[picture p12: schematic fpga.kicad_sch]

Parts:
C75, C79, C80, C81, C82: C_100n_0402; 0402-cap; MPN GRM155R61H104KE14D
D5: LTST-C190GKT; LED_0603; MPN LTST-C190GKT
D6: LTST-C190KRKT; LED_0603; MPN LTST-C190KRKT
J7: 2X05; SHF-105-01-X-D-SM; MPN SHF-105-01-L-D-SM
Q6: 2N7002; SOT-23-3; MPN 2N7002
R39, R66, R67, R69, R71, R75, R76, R77, R78, R80, R82, R85, R86, R88, R92, R94, R95, R96: R_0R_0402; 0402-res; MPN ERJ2GE0R00X
R58, R65: R_0R_0402; 0603-res; MPN CR0603-J/-000ELF
R68, R81, R91, R97: R_10k_0402; 0402-res; MPN CRCW040210K0FKEDHP
R70, R72, R84: R_100R_0402; 0402-res; MPN CR0402-FX-1000GLF
R79: R_1k_0402; 0402-res; MPN CR0402-FX-1001GLF
R83, R87, R90: R_4k7_0402; 0402-res; MPN MCS04020C4701FE000
R89, R93: R_2k2_0402; 0402-res; MPN RC0402FR-072K2L
S1: B3U-3000PM; B3U-3000P; MPN B3U-3000PM
TP15, TP16, TP17, TP18, TP19, TP20, TP21, TP22: TP_SMD_0_75MM; Testpoint_smd_0_75mm
U11: LIFCL-40-9BG256C; BGA-256_16x16_14.0x14.0mm; MPN LIFCL-40-9BG256C
U17: SC18IS602BIPW; SC18IS602B; MPN SC18IS602BIPW
U18: W25Q32JVSSIQ; SOIC-8_W5.3mm; MPN W25Q32JVSSIQ
Y2: OSC40M-3.3_S5; OSC-4_5.0x3.2mm; MPN OSC40M-3.3/S5

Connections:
40MHz_3V3: Y2.3 (OUT); also elsewhere on the board
/FPGA/DONE: R77.1, R81.1, R84.1, TP19.1, U11.B16 (PT76B/DONE)
/FPGA/DONE_SOFT: R77.2, U17.10 (GPIO2/~SS2)
/FPGA/INITN: D6.2, R86.1, R91.1, TP22.1, U11.D11 (PT74A/INITN)
/FPGA/INITN_SOFT: R86.2, U17.13 (GPIO3/~SS3)
/FPGA/MISO_SOFT: R71.2, U17.5 (MISO)
/FPGA/MOSI_SOFT: R69.2, U17.6 (MOSI)
/FPGA/PROGRAMN: R67.1, R68.1, R70.1, U11.C12 (PT74B/PROGRAMN)
/FPGA/PROGRAMN_SOFT: R67.2, U17.2 (GPIO1/~SS1)
/FPGA/SPI_CLK: R75.1, TP20.1, U11.C16 (PT76A/MCLK/PCLKT0_0), U18.6 (SCLK)
/FPGA/SPI_CLK_SOFT: R75.2, U17.11 (SPICLK)
/FPGA/SPI_DQ0_MOSI: R69.1, TP15.1, U11.C14 (PT78B/MOSI/MD0), U18.5 (SI/IO0)
/FPGA/SPI_DQ1_MISO: R71.1, TP16.1, U11.D16 (PT80A/MISO/MD1), U18.2 (SO/IO1)
/FPGA/SPI_DQ2: R83.1, TP17.1, U11.D15 (PT80B/MD2), U18.3 (~WP/IO2); also elsewhere on the board
/FPGA/SPI_DQ3: R87.1, TP18.1, U11.D12 (PT82A/MD3), U18.7 (~HOLD/IO3); also elsewhere on the board
/FPGA/~FLASH_CS_SOFT: R76.1, U17.1 (GPIO0/~SS0)
/FPGA/~FLASH_CS: R82.1, TP21.1, U11.C15 (PT78A/MCSN/PCLKT0_1)
JTAG_EN: R96.2, R97.2; also elsewhere on the board
LED0: U11.E15 (PT84A); also elsewhere on the board
LED1: U11.E16 (PT84B); also elsewhere on the board
unnamed: C80.1, R70.2, R72.1
unnamed: D5.1, R89.1
unnamed: D5.2, Q6.3 (D)
unnamed: D6.1, R93.1
unnamed: J7.2, R88.1
unnamed: J7.4, R92.1
unnamed: J7.6, R94.1
unnamed: J7.8, R95.1
unnamed: J7.10, R96.1
unnamed: Q6.1 (G), R84.2
unnamed: R39.1, Y2.1 (EN)
unnamed: R58.1, U17.7 (SDA)
unnamed: R65.1, U17.8 (SCL)
unnamed: R66.1, U17.3 (~RESET)
unnamed: R72.2, S1.2
unnamed: R76.2, R82.2, R90.1, U18.1 (~CS)
unnamed: R78.1, U17.16 (A2)
unnamed: R79.1, U17.9 (~INT)
unnamed: R80.1, U17.15 (A1)
unnamed: R85.1, U17.14 (A0)
SCL: R65.2; also elsewhere on the board
SDA: R58.2; also elsewhere on the board
TCK: R92.2; also elsewhere on the board
TDI: R95.2; also elsewhere on the board
TDO: R94.2; also elsewhere on the board
TMS: R88.2; also elsewhere on the board

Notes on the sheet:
DONE
FPGA
OSCILLATOR
OPTIONAL, NORMALLY DNP
FPGA CONFIGURATION
JTAG CONNECTOR
CONFIGURATION FLASH
I2C TO SPI BRIDGE
INITN
PROGRAMN

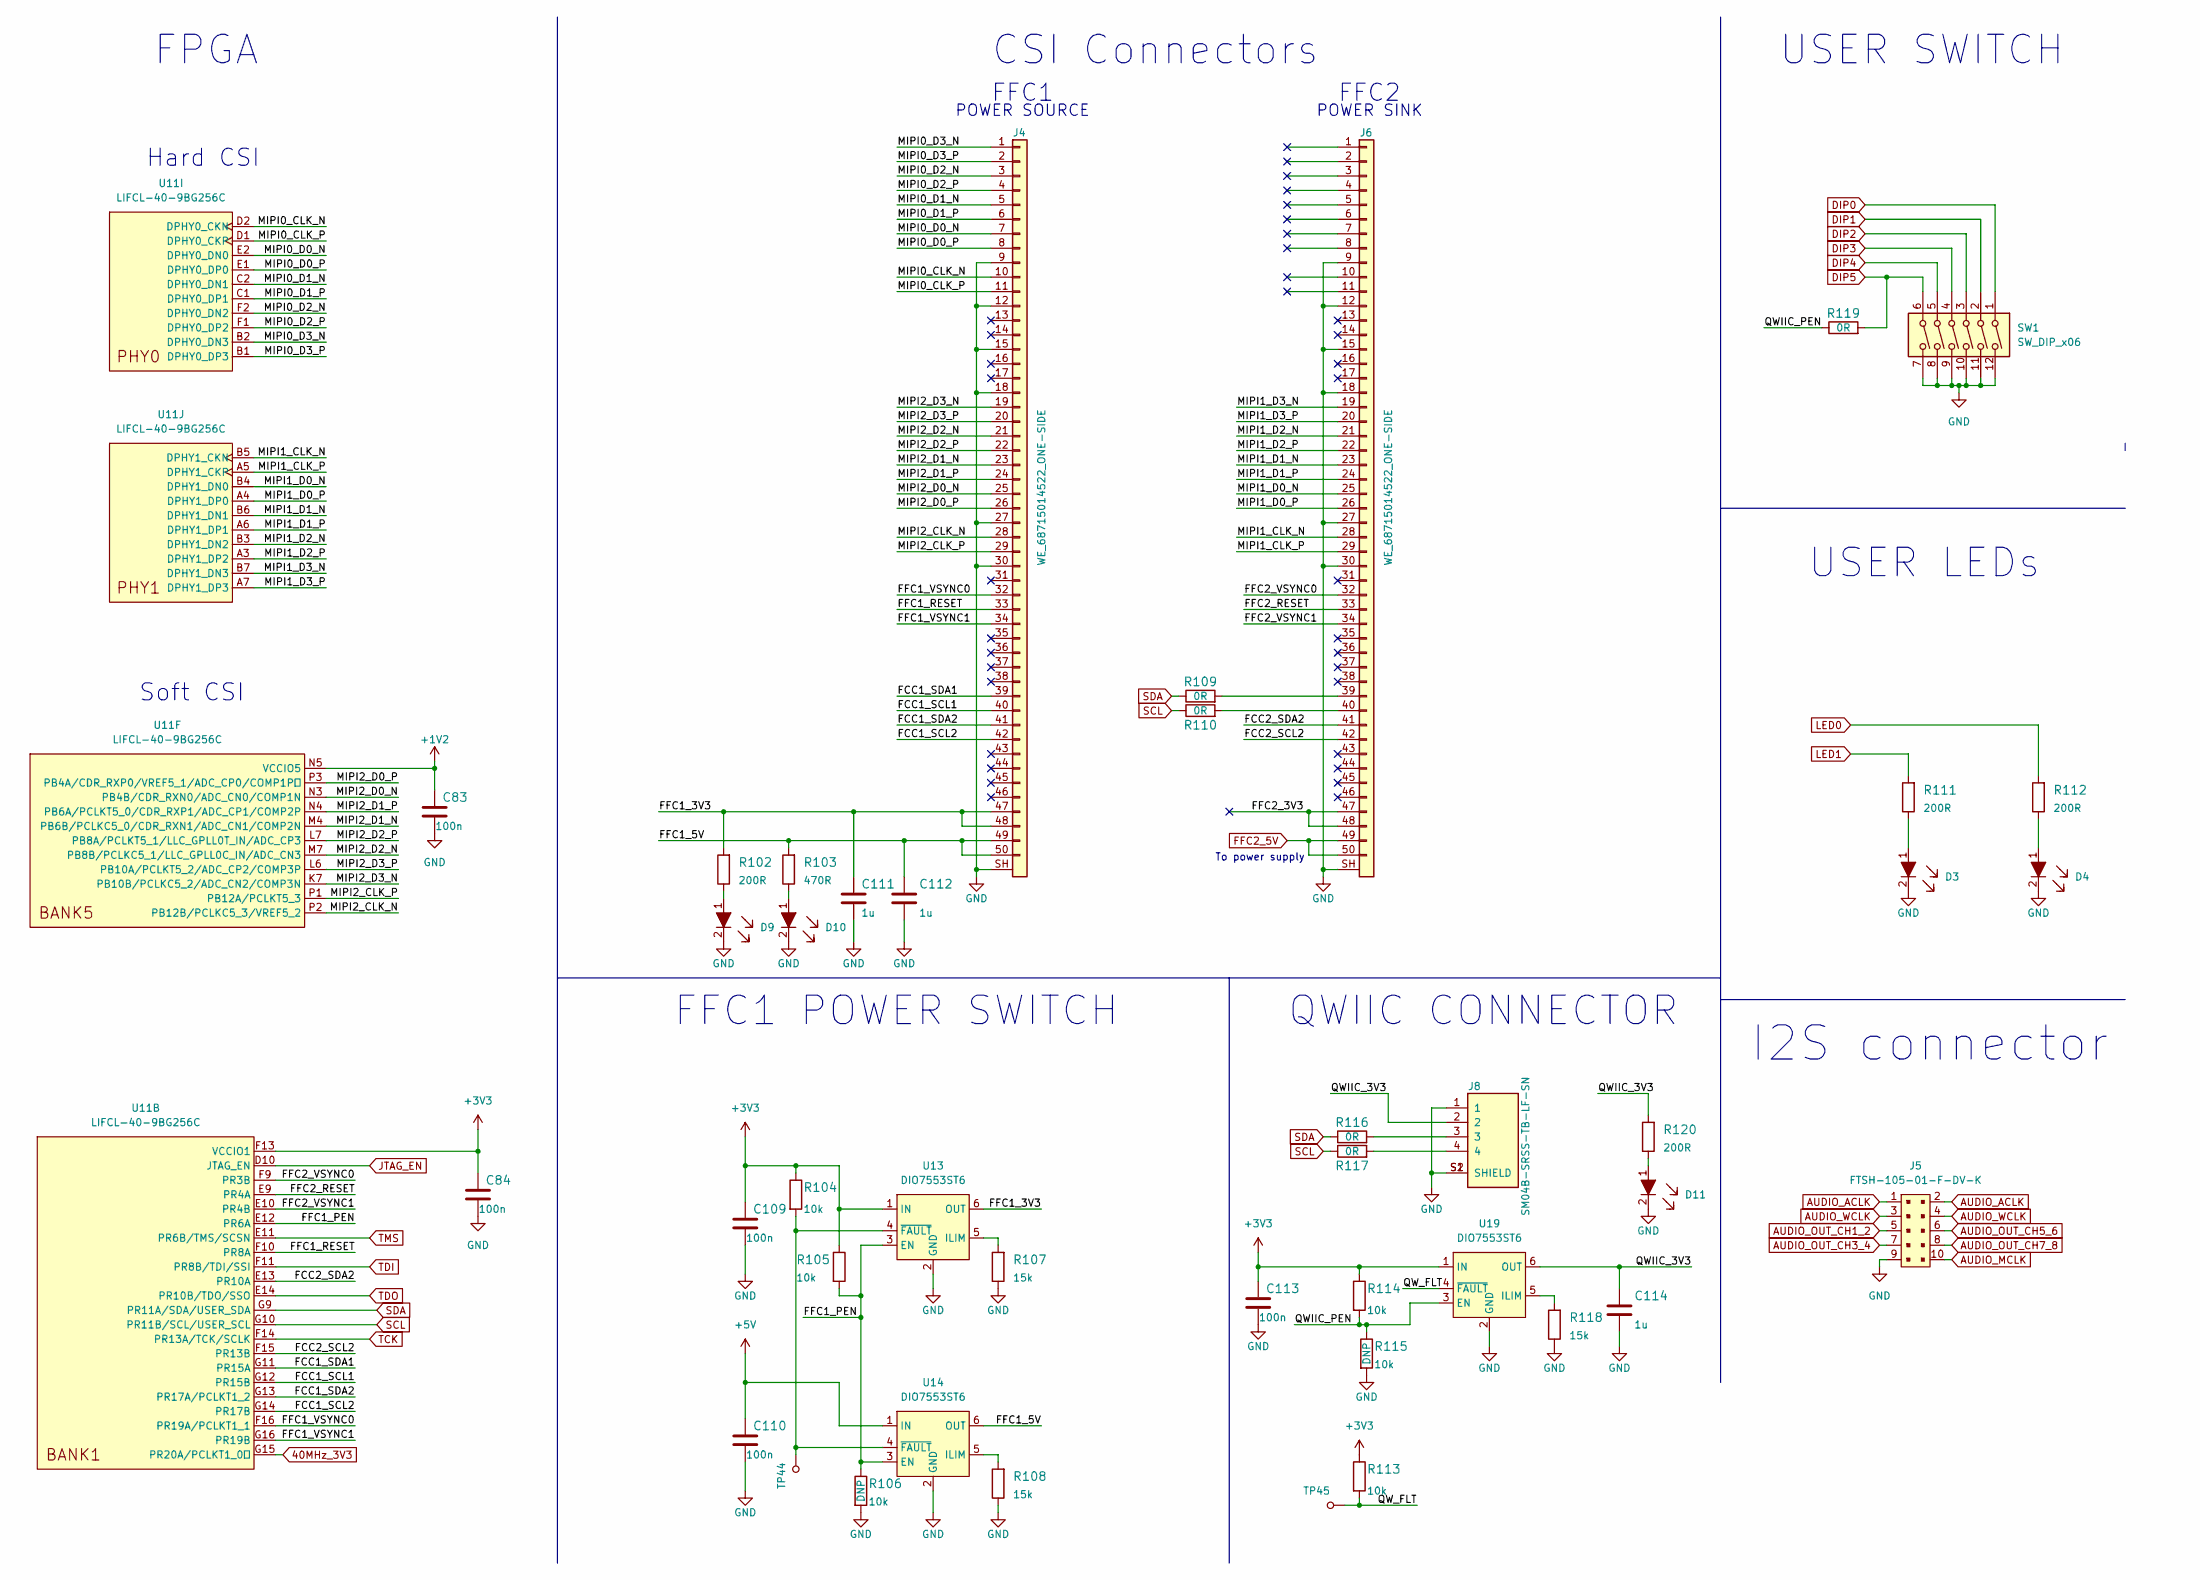
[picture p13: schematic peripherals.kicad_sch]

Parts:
C83, C84, C109, C110, C113: C_100n_0402; 0402-cap; MPN GRM155R61H104KE14D
C111, C112, C114: C_1u_0603; 0603-cap; MPN 0603YD105KAT2A
D3, D4, D9, D10, D11: LTST-C190GKT; LED_0603; MPN LTST-C190GKT
J4, J6: WE_68715014522_ONE-SIDE; MPN 68715014522
J5: FTSH-105-01-F-DV-K; PinHeader_2x5_P1.27_SMD; MPN FTSH-105-01-F-DV-K
J8: SM04B-SRSS-TB-LF-SN; MPN SM04B-SRSS-TB-LF-SN
R102, R111, R112, R120: R_200R_0603; 0603-res; MPN ERJ-UP3F2000V
R103: R_470R_0603; 0603-res; MPN CR0603-JW-471GLF
R104, R105, R106, R113, R114, R115: R_10k_0603; 0603-res; MPN CR0603-JW-103ELF
R107, R108, R118: R_15k_0603; 0603-res; MPN CR0603-FX-1502ELF
R109, R110, R116, R117, R119: R_0R_0603; 0603-res; MPN CR0603-J/-000ELF
SW1: SW_DIP_x06; SW_SPST_6_Slide_MCDHN-06F-T-V_P1.27mm; MPN MCDHN-06F-T-V
TP44, TP45: TP_SMD_0_75MM; Testpoint_smd_0_75mm
U11: LIFCL-40-9BG256C; BGA-256_16x16_14.0x14.0mm; MPN LIFCL-40-9BG256C
U13, U14, U19: DIO7553ST6; SOT23-6L; MPN DIO7553ST6

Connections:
40MHz_3V3: U11.G15 (PR20A/PCLKT1_0); also elsewhere on the board
+1V2: C83.1, U11.N5 (VCCIO5); also elsewhere on the board
+5V: C110.1, U14.1 (IN); also elsewhere on the board
/Peripherals/FCC1_SCL1: J4.40, U11.G12 (PR15B)
/Peripherals/FCC1_SCL2: J4.42, U11.G14 (PR17B)
/Peripherals/FCC1_SDA1: J4.39, U11.G11 (PR15A)
/Peripherals/FCC1_SDA2: J4.41, U11.G13 (PR17A/PCLKT1_2)
/Peripherals/FCC2_SCL2: J6.42, U11.F15 (PR13B)
/Peripherals/FCC2_SDA2: J6.41, U11.E13 (PR10A)
/Peripherals/FFC1_3V3: C111.1, J4.47, J4.48, R102.2, U13.6 (OUT)
/Peripherals/FFC1_5V: C112.1, J4.49, J4.50, R103.2, U14.6 (OUT)
/Peripherals/FFC1_PEN: R105.2, R106.1, U11.E12 (PR6A), U13.3 (EN), U14.3 (EN)
/Peripherals/FFC1_RESET: J4.33, U11.F10 (PR8A)
/Peripherals/FFC1_VSYNC0: J4.32, U11.F16 (PR19A/PCLKT1_1)
/Peripherals/FFC1_VSYNC1: J4.34, U11.G16 (PR19B)
/Peripherals/FFC2_3V3: J6.47, J6.48
/Peripherals/FFC2_RESET: J6.33, U11.E9 (PR4A)
/Peripherals/FFC2_VSYNC0: J6.32, U11.F9 (PR3B)
/Peripherals/FFC2_VSYNC1: J6.34, U11.E10 (PR4B)
/Peripherals/MIPI0_CLK_N: J4.10, U11.D2 (DPHY0_CKN)
/Peripherals/MIPI0_CLK_P: J4.11, U11.D1 (DPHY0_CKP)
/Peripherals/MIPI0_D0_N: J4.7, U11.E2 (DPHY0_DN0)
/Peripherals/MIPI0_D0_P: J4.8, U11.E1 (DPHY0_DP0)
/Peripherals/MIPI0_D1_N: J4.5, U11.C2 (DPHY0_DN1)
/Peripherals/MIPI0_D1_P: J4.6, U11.C1 (DPHY0_DP1)
/Peripherals/MIPI0_D2_N: J4.3, U11.F2 (DPHY0_DN2)
/Peripherals/MIPI0_D2_P: J4.4, U11.F1 (DPHY0_DP2)
/Peripherals/MIPI0_D3_N: J4.1, U11.B2 (DPHY0_DN3)
/Peripherals/MIPI0_D3_P: J4.2, U11.B1 (DPHY0_DP3)
/Peripherals/MIPI1_CLK_N: J6.28, U11.B5 (DPHY1_CKN)
/Peripherals/MIPI1_CLK_P: J6.29, U11.A5 (DPHY1_CKP)
/Peripherals/MIPI1_D0_N: J6.25, U11.B4 (DPHY1_DN0)
/Peripherals/MIPI1_D0_P: J6.26, U11.A4 (DPHY1_DP0)
/Peripherals/MIPI1_D1_N: J6.23, U11.B6 (DPHY1_DN1)
/Peripherals/MIPI1_D1_P: J6.24, U11.A6 (DPHY1_DP1)
/Peripherals/MIPI1_D2_N: J6.21, U11.B3 (DPHY1_DN2)
/Peripherals/MIPI1_D2_P: J6.22, U11.A3 (DPHY1_DP2)
/Peripherals/MIPI1_D3_N: J6.19, U11.B7 (DPHY1_DN3)
/Peripherals/MIPI1_D3_P: J6.20, U11.A7 (DPHY1_DP3)
/Peripherals/MIPI2_CLK_N: J4.28, U11.P2 (PB12B/PCLKC5_3/VREF5_2)
/Peripherals/MIPI2_CLK_P: J4.29, U11.P1 (PB12A/PCLKT5_3)
/Peripherals/MIPI2_D0_N: J4.25, U11.N3 (PB4B/CDR_RXN0/ADC_CN0/COMP1N)
/Peripherals/MIPI2_D0_P: J4.26, U11.P3 (PB4A/CDR_RXP0/VREF5_1/ADC_CP0/COMP1P)
/Peripherals/MIPI2_D1_N: J4.23, U11.M4 (PB6B/PCLKC5_0/CDR_RXN1/ADC_CN1/COMP2N)
/Peripherals/MIPI2_D1_P: J4.24, U11.N4 (PB6A/PCLKT5_0/CDR_RXP1/ADC_CP1/COMP2P)
/Peripherals/MIPI2_D2_N: J4.21, U11.M7 (PB8B/PCLKC5_1/LLC_GPLL0C_IN/ADC_CN3)
/Peripherals/MIPI2_D2_P: J4.22, U11.L7 (PB8A/PCLKT5_1/LLC_GPLL0T_IN/ADC_CP3)
/Peripherals/MIPI2_D3_N: J4.19, U11.K7 (PB10B/PCLKC5_2/ADC_CN2/COMP3N)
/Peripherals/MIPI2_D3_P: J4.20, U11.L6 (PB10A/PCLKT5_2/ADC_CP2/COMP3P)
/Peripherals/QWIIC_3V3: C114.1, J8.2, R120.2, U19.6 (OUT)
/Peripherals/QWIIC_PEN: R114.2, R115.1, R119.1, U19.3 (EN)
/Peripherals/QW_FLT: R113.2, TP45.1, U19.4 (~FAULT)
AUDIO_ACLK: J5.1, J5.2; also elsewhere on the board
AUDIO_MCLK: J5.10; also elsewhere on the board
AUDIO_OUT_CH1_2: J5.5; also elsewhere on the board
AUDIO_OUT_CH3_4: J5.7; also elsewhere on the board
AUDIO_OUT_CH5_6: J5.6; also elsewhere on the board
AUDIO_OUT_CH7_8: J5.8; also elsewhere on the board
AUDIO_WCLK: J5.3, J5.4; also elsewhere on the board
DIP0: SW1.1; also elsewhere on the board
DIP1: SW1.2; also elsewhere on the board
DIP2: SW1.3; also elsewhere on the board
DIP3: SW1.4; also elsewhere on the board
DIP4: SW1.5; also elsewhere on the board
DIP5: R119.2, SW1.6; also elsewhere on the board
FFC2_5V: J6.49, J6.50; also elsewhere on the board
JTAG_EN: U11.D10 (JTAG_EN); also elsewhere on the board
LED0: R112.2; also elsewhere on the board
LED1: R111.2; also elsewhere on the board
unnamed: D3.1, R111.1
unnamed: D4.1, R112.1
unnamed: D9.1, R102.1
unnamed: D10.1, R103.1
unnamed: D11.1, R120.1
unnamed: J6.39, R109.2
unnamed: J6.40, R110.2
unnamed: J8.3, R116.2
unnamed: J8.4, R117.2
unnamed: R104.2, TP44.1, U13.4 (~FAULT), U14.4 (~FAULT)
unnamed: R107.2, U13.5 (ILIM)
unnamed: R108.2, U14.5 (ILIM)
unnamed: R118.2, U19.5 (ILIM)
SCL: R110.1, R117.1, U11.G10 (PR11B/SCL/USER_SCL); also elsewhere on the board
SDA: R109.1, R116.1, U11.G9 (PR11A/SDA/USER_SDA); also elsewhere on the board
TCK: U11.F14 (PR13A/TCK/SCLK); also elsewhere on the board
TDI: U11.F11 (PR8B/TDI/SSI); also elsewhere on the board
TDO: U11.E14 (PR10B/TDO/SSO); also elsewhere on the board
TMS: U11.E11 (PR6B/TMS/SCSN); also elsewhere on the board

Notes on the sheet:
Soft CSI
FFC1 POWER SWITCH
POWER SOURCE
QWIIC CONNECTOR
FPGA
FFC1
USER LEDs
CSI Connectors
I2S connector
USER SWITCH
FFC2
Hard CSI
To power supply
POWER SINK

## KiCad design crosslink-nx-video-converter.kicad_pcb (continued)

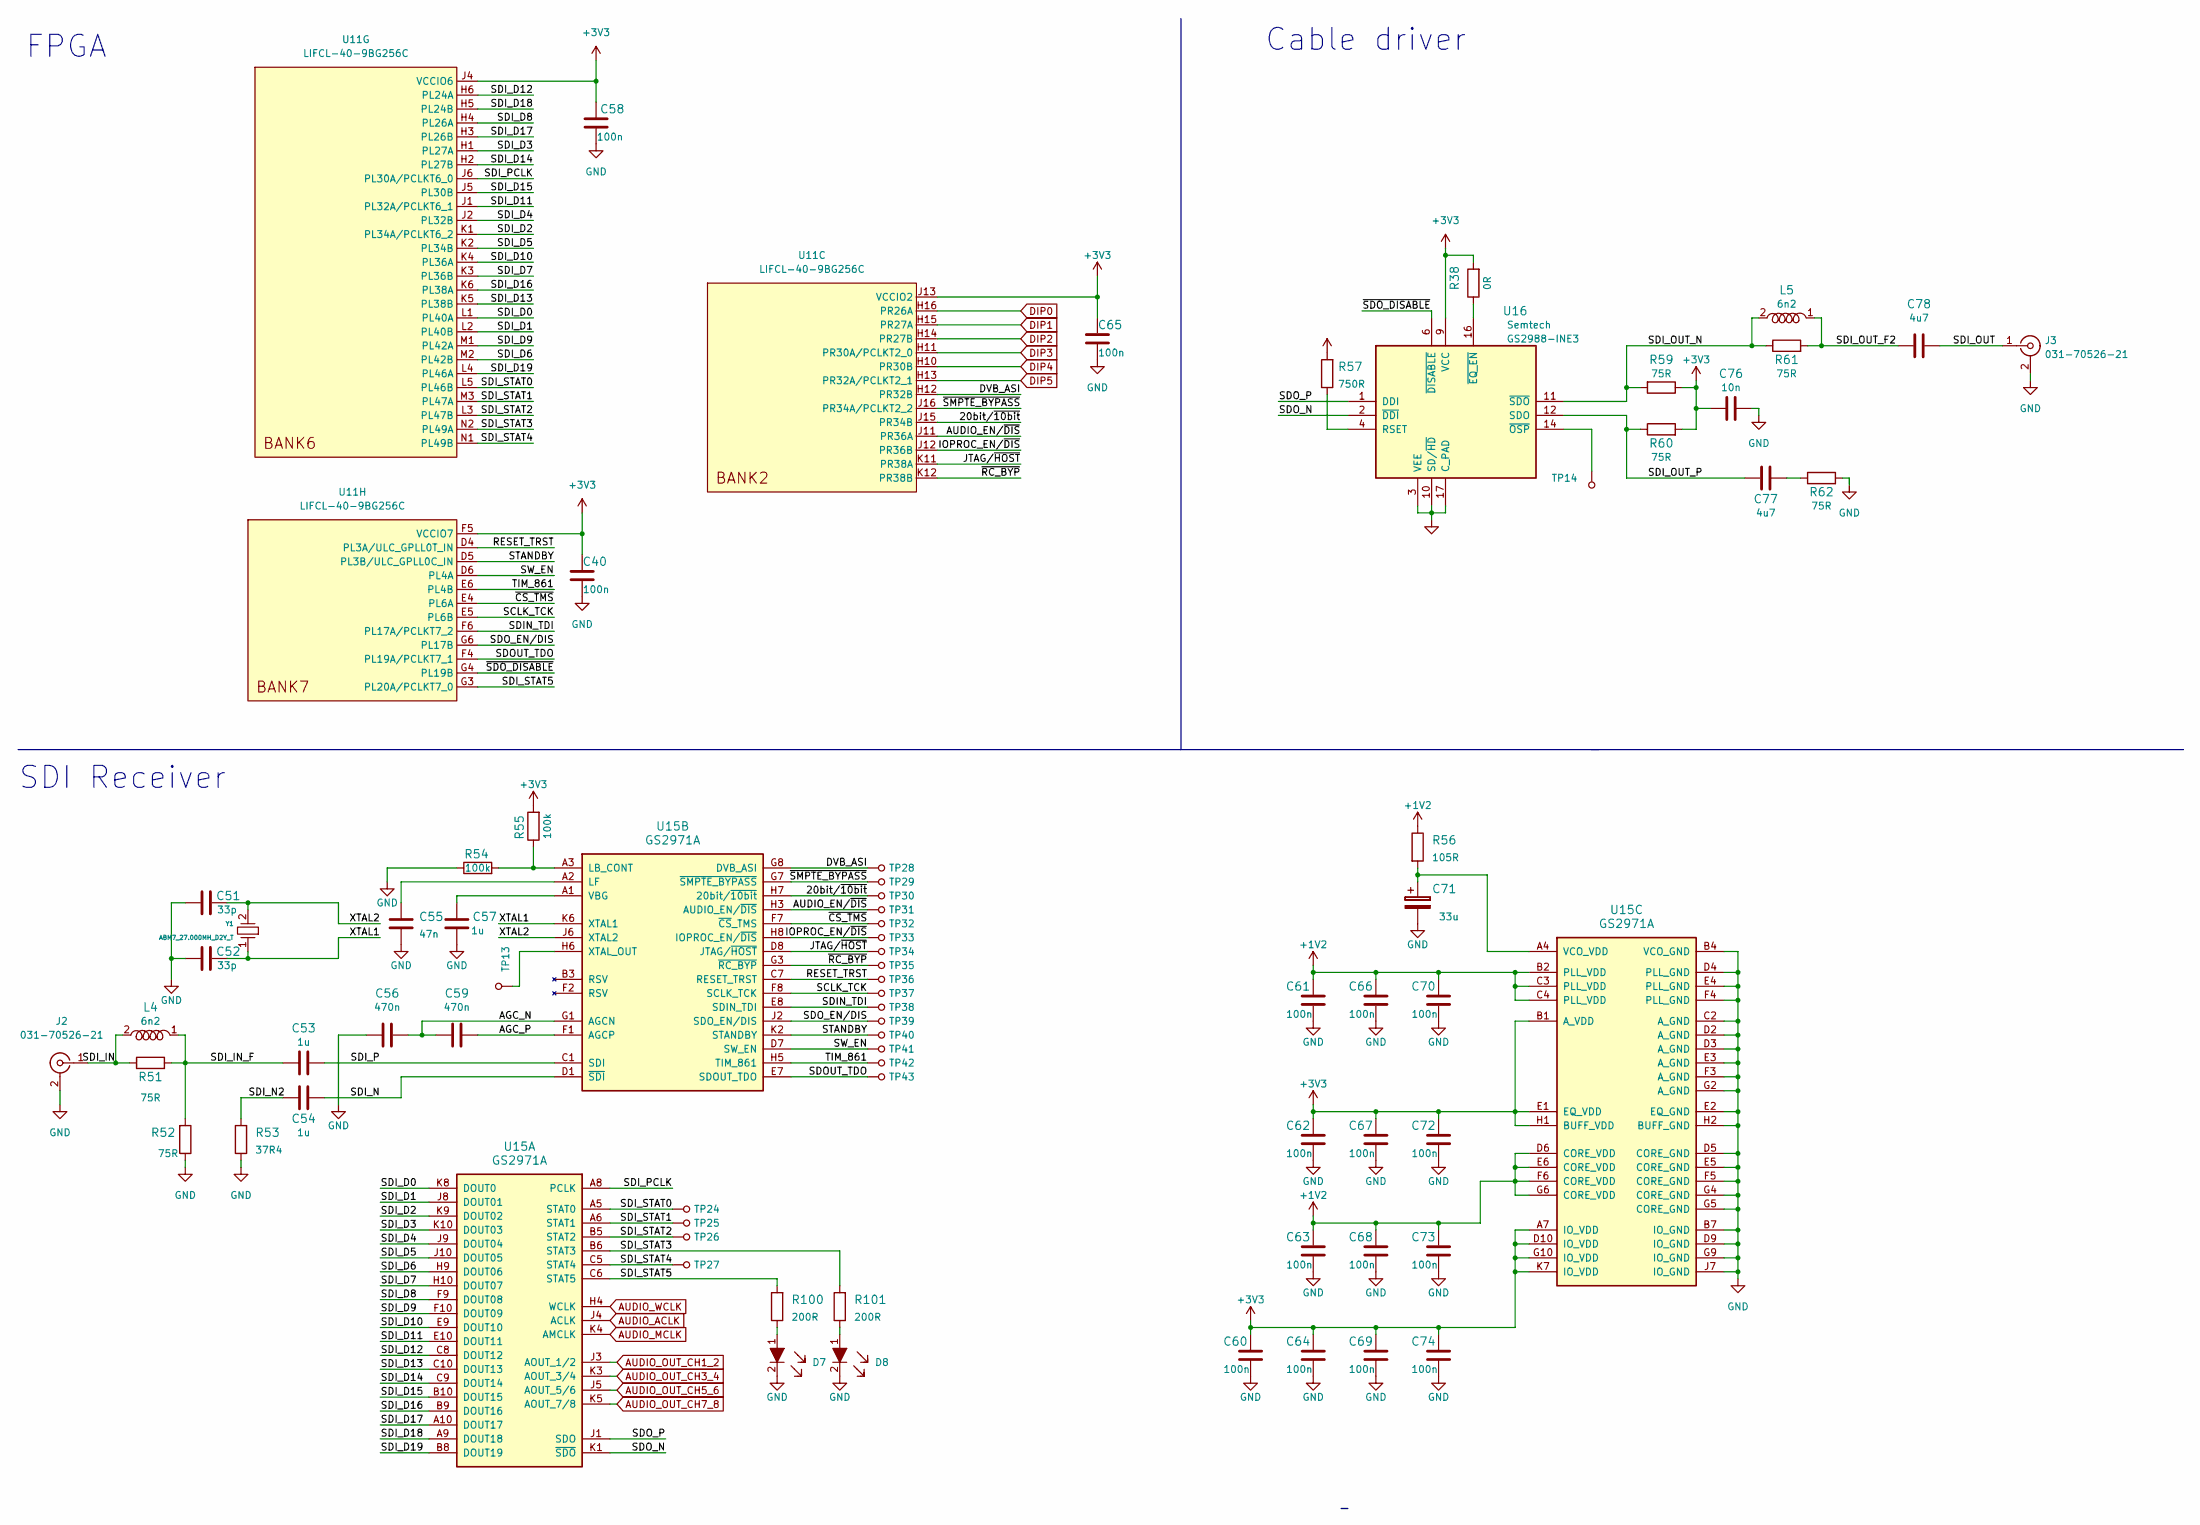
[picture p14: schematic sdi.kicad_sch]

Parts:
C40, C58, C60, C61, C62, C63, C64, C65, C66, C67, C68, C69, C70, C72, C73, C74: C_100n_0402; 0402-cap; MPN GRM155R61H104KE14D
C51, C52: C_33p_0402; 0402-cap; MPN MC0402N330J500CT
C53, C54, C57: C_1u_0402; 0402-cap; MPN C1005X6S1A105K050BC
C55: C_47n_0402; 0402-cap; MPN MC0402X473K160CT
C56, C59: C_470n_0402; 0402-cap; MPN C1005X5R1E474M050BB
C71: C_33u_0603; 0603-cap; MPN F980G336MMA
C76: C_10n_0402; 0402-cap; MPN 04025G103ZAT2A
C77, C78: C_4u7_0402; 0402-cap; MPN GRM155R61A475MEAAD
D7, D8: LTST-C190GKT; LED_0603; MPN LTST-C190GKT
J2, J3: 031-70526-21; BNC_Edge_Conn; MPN 031-70526-21
L4, L5: L_0402_6n2; 0402-cap; MPN LQW15AN6N2C00D
R38: R_0R_0402; 0402-res; MPN ERJ2GE0R00X
R51, R52, R59, R60, R61, R62: R_75R_0402; 0402-res; MPN RC0402FR-0775RL
R53: R_37R4_0402; 0402-res; MPN MCWR04X37R4FTL
R54, R55: R_100k_0402; 0402-res; MPN CRCW0402100KFKEDHP
R56: R_105R_0402; 0402-res; MPN MC00625W04021105R
R57: R_750R_0402; 0402-res; MPN RC0402FR-07750RL
R100, R101: R_200R_0603; 0603-res; MPN ERJ-UP3F2000V
TP13, TP14, TP24, TP25, TP26, TP27, TP28, TP29, TP30, TP31, TP32, TP33, TP34, TP35, TP36, TP37, TP38, TP39, TP40, TP41, TP42, TP43: TP_SMD_0_75MM; Testpoint_smd_0_75mm
U11: LIFCL-40-9BG256C; BGA-256_16x16_14.0x14.0mm; MPN LIFCL-40-9BG256C
U15: GS2971A; BGA100_11x11mm; MPN GS2971A
U16: GS2988; QFN-16_EP_4x4_Pitch0.65mm; MPN GS2988-INE3
Y1: ABM7_27.000MH_D2Y_T; ABM7_OSC; MPN ABM7-27.000MHZ-D2Y-T

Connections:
+1V2: C61.1, C63.1, C66.1, C68.1, C70.1, C73.1, R56.1, U15.B2 (PLL_VDD), U15.C3 (PLL_VDD), U15.C4 (PLL_VDD), U15.D6 (CORE_VDD), U15.E6 (CORE_VDD), U15.F6 (CORE_VDD), U15.G6 (CORE_VDD); also elsewhere on the board
/SDI/20bit/~10bit: TP30.1, U11.J15 (PR34B), U15.H7 (20bit/~10bit)
/SDI/AGC_N: C56.2, C59.1, U15.G1 (AGCN)
/SDI/AGC_P: C59.2, U15.F1 (AGCP)
/SDI/AUDIO_EN/~DIS: TP31.1, U11.J11 (PR36A), U15.H3 (AUDIO_EN/~DIS)
/SDI/DVB_ASI: TP28.1, U11.H12 (PR32B), U15.G8 (DVB_ASI)
/SDI/IOPROC_EN/~DIS: TP33.1, U11.J12 (PR36B), U15.H8 (IOPROC_EN/~DIS)
/SDI/JTAG/~HOST: TP34.1, U11.K11 (PR38A), U15.D8 (JTAG/~HOST)
/SDI/RESET_TRST: TP36.1, U11.D4 (PL3A/ULC_GPLL0T_IN), U15.C7 (RESET_TRST)
/SDI/SCLK_TCK: TP37.1, U11.E5 (PL6B), U15.F8 (SCLK_TCK)
/SDI/SDIN_TDI: TP38.1, U11.F6 (PL17A/PCLKT7_2), U15.E8 (SDIN_TDI)
/SDI/SDI_D0: U11.L1 (PL40A), U15.K8 (DOUT0)
/SDI/SDI_D1: U11.L2 (PL40B), U15.J8 (DOUT01)
/SDI/SDI_D2: U11.K1 (PL34A/PCLKT6_2), U15.K9 (DOUT02)
/SDI/SDI_D3: U11.H1 (PL27A), U15.K10 (DOUT03)
/SDI/SDI_D4: U11.J2 (PL32B), U15.J9 (DOUT04)
/SDI/SDI_D5: U11.K2 (PL34B), U15.J10 (DOUT05)
/SDI/SDI_D6: U11.M2 (PL42B), U15.H9 (DOUT06)
/SDI/SDI_D7: U11.K3 (PL36B), U15.H10 (DOUT07)
/SDI/SDI_D8: U11.H4 (PL26A), U15.F9 (DOUT08)
/SDI/SDI_D9: U11.M1 (PL42A), U15.F10 (DOUT09)
/SDI/SDI_D10: U11.K4 (PL36A), U15.E9 (DOUT10)
/SDI/SDI_D11: U11.J1 (PL32A/PCLKT6_1), U15.E10 (DOUT11)
/SDI/SDI_D12: U11.H6 (PL24A), U15.C8 (DOUT12)
/SDI/SDI_D13: U11.K5 (PL38B), U15.C10 (DOUT13)
/SDI/SDI_D14: U11.H2 (PL27B), U15.C9 (DOUT14)
/SDI/SDI_D15: U11.J5 (PL30B), U15.B10 (DOUT15)
/SDI/SDI_D16: U11.K6 (PL38A), U15.B9 (DOUT16)
/SDI/SDI_D17: U11.H3 (PL26B), U15.A10 (DOUT17)
/SDI/SDI_D18: U11.H5 (PL24B), U15.A9 (DOUT18)
/SDI/SDI_D19: U11.L4 (PL46A), U15.B8 (DOUT19)
/SDI/SDI_IN: J2.1 (In), L4.2, R51.1
/SDI/SDI_IN_F: C53.1, L4.1, R51.2, R52.2
/SDI/SDI_N: C54.2, U15.D1 (~SDI)
/SDI/SDI_N2: C54.1, R53.2
/SDI/SDI_OUT: C78.2, J3.1 (In)
/SDI/SDI_OUT_F2: C78.1, L5.1, R61.2
/SDI/SDI_OUT_N: L5.2, R59.2, R61.1, U16.11 (~SDO)
/SDI/SDI_OUT_P: C77.1, R60.1, U16.12 (SDO)
/SDI/SDI_P: C53.2, U15.C1 (SDI)
/SDI/SDI_PCLK: U11.J6 (PL30A/PCLKT6_0), U15.A8 (PCLK)
/SDI/SDI_STAT0: TP24.1, U11.L5 (PL46B), U15.A5 (STAT0)
/SDI/SDI_STAT1: TP25.1, U11.M3 (PL47A), U15.A6 (STAT1)
/SDI/SDI_STAT2: TP26.1, U11.L3 (PL47B), U15.B5 (STAT2)
/SDI/SDI_STAT3: R101.2, U11.N2 (PL49A), U15.B6 (STAT3)
/SDI/SDI_STAT4: TP27.1, U11.N1 (PL49B), U15.C5 (STAT4)
/SDI/SDI_STAT5: R100.2, U11.G3 (PL20A/PCLKT7_0), U15.C6 (STAT5)
/SDI/SDOUT_TDO: TP43.1, U11.F4 (PL19A/PCLKT7_1), U15.E7 (SDOUT_TDO)
/SDI/SDO_EN/DIS: TP39.1, U11.G6 (PL17B), U15.J2 (SDO_EN/DIS)
/SDI/SDO_N: U15.K1 (~SDO), U16.2 (~DDI)
/SDI/SDO_P: U15.J1 (SDO), U16.1 (DDI)
/SDI/STANDBY: TP40.1, U11.D5 (PL3B/ULC_GPLL0C_IN), U15.K2 (STANDBY)
/SDI/SW_EN: TP41.1, U11.D6 (PL4A), U15.D7 (SW_EN)
/SDI/TIM_861: TP42.1, U11.E6 (PL4B), U15.H5 (TIM_861)
/SDI/~CS_TMS: TP32.1, U11.E4 (PL6A), U15.F7 (~CS_TMS)
/SDI/~RC_BYP: TP35.1, U11.K12 (PR38B), U15.G3 (~RC_BYP)
/SDI/~SDO_DISABLE: U11.G4 (PL19B), U16.6 (~DISABLE)
/SDI/~SMPTE_BYPASS: TP29.1, U11.J16 (PR34A/PCLKT2_2), U15.G7 (~SMPTE_BYPASS)
AUDIO_ACLK: U15.J4 (ACLK); also elsewhere on the board
AUDIO_MCLK: U15.K4 (AMCLK); also elsewhere on the board
AUDIO_OUT_CH1_2: U15.J3 (AOUT_1/2); also elsewhere on the board
AUDIO_OUT_CH3_4: U15.K3 (AOUT_3/4); also elsewhere on the board
AUDIO_OUT_CH5_6: U15.J5 (AOUT_5/6); also elsewhere on the board
AUDIO_OUT_CH7_8: U15.K5 (AOUT_7/8); also elsewhere on the board
AUDIO_WCLK: U15.H4 (WCLK); also elsewhere on the board
DIP0: U11.H16 (PR26A); also elsewhere on the board
DIP1: U11.H15 (PR27A); also elsewhere on the board
DIP2: U11.H14 (PR27B); also elsewhere on the board
DIP3: U11.H11 (PR30A/PCLKT2_0); also elsewhere on the board
DIP4: U11.H10 (PR30B); also elsewhere on the board
DIP5: U11.H13 (PR32A/PCLKT2_1); also elsewhere on the board
unnamed: C55.1, U15.A2 (LF)
unnamed: C57.2, U15.A1 (VBG)
unnamed: C71.1, R56.2, U15.A4 (VCO_VDD)
unnamed: C77.2, R62.1
unnamed: D7.1, R100.1
unnamed: D8.1, R101.1
unnamed: R38.1, U16.16 (~EQ_EN)
unnamed: R54.2, R55.1, U15.A3 (LB_CONT)
unnamed: R57.1, U16.4 (RSET)
unnamed: TP13.1, U15.H6 (XTAL_OUT)
unnamed: TP14.1, U16.14 (~OSP)

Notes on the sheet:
Cable driver
FPGA
SDI Receiver

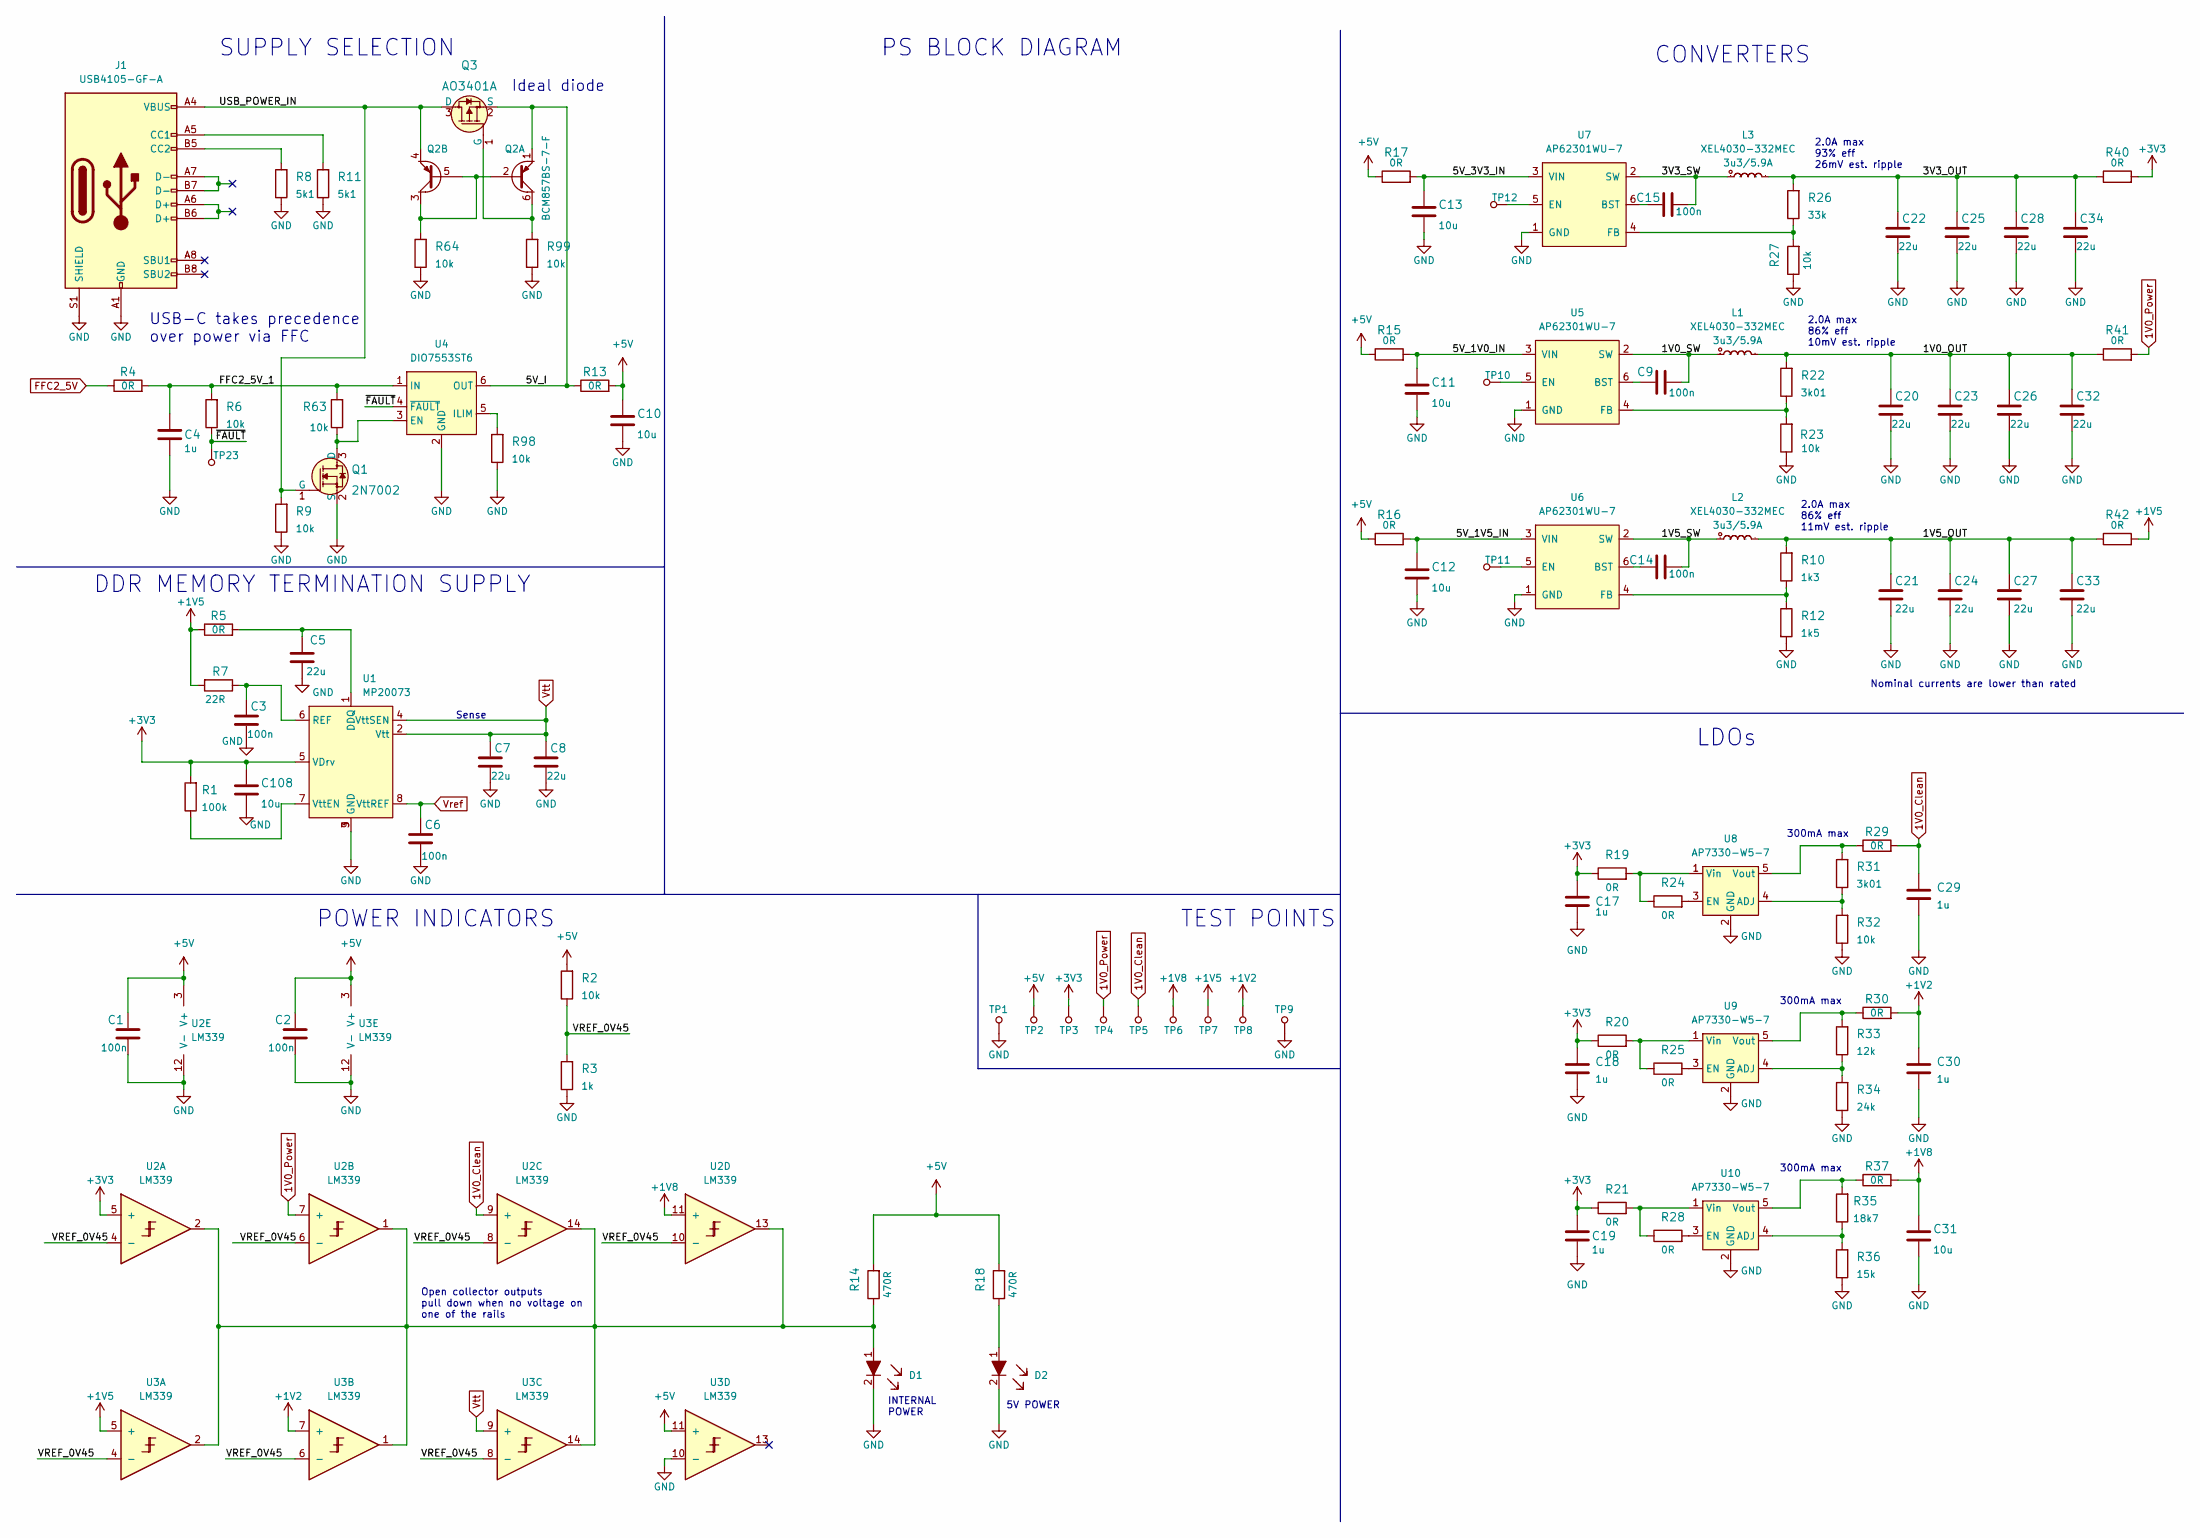
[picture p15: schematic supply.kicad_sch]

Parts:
C1, C2, C3, C6, C9, C14, C15: C_100n_0402; 0402-cap; MPN GRM155R61H104KE14D
C4, C17, C18, C19, C29, C30: C_1u_0603; 0603-cap; MPN 0603YD105KAT2A
C5, C7, C8, C20, C21, C22, C23, C24, C25, C26, C27, C28, C32, C33, C34: C_22u_0603; 0603-cap; MPN GRM188R60J226MEA0D
C10, C11, C12, C13, C31, C108: C_10u_0603; 0603-cap; MPN GRM188R61A106KE69D
D1, D2: LTST-C190GKT; LED_0603; MPN LTST-C190GKT
J1: USB4105-GF-A; GCT_USB4105-GF-A; MPN USB4105-GF-A
L1, L2, L3: XEL4030-332MEC; Coilcraft-XEL4030; MPN XEL4030-332MEC
Q1: 2N7002; SOT-23-3; MPN 2N7002
Q2: BCM857BS-7-F; SOT-363; MPN BCM857BS-7-F
Q3: AO3401A; SOT-23-3; MPN AO3401A
R1: R_100k_0402; 0402-res; MPN CRCW0402100KFKEDHP
R2, R6, R9, R23, R27, R32, R63, R64, R98, R99: R_10k_0402; 0402-res; MPN CRCW040210K0FKEDHP
R3: R_1k_0402; 0402-res; MPN CR0402-FX-1001GLF
R4, R13: R_0R_1206; 1206-res; MPN MCMR12X000_PTL
R5, R15, R16, R17, R40, R41, R42: R_0R_0805; 0805-res; MPN CRCW08050000Z0EA
R7: R_22R_0402; 0402-res; MPN CRCW040222R0FKED
R8, R11: R_5k1_0402; 0402-res; MPN SFR01MZPJ512
R10: R_1k3_0402; 0402-res; MPN CR0402-FX-1301GLF
R12: R_1k5_0402; 0402-res; MPN MP000515
R14, R18: R_470R_0402; 0402-res; MPN CRCW0402470RFKED
R19, R20, R21, R24, R25, R28: R_0R_0402; 0402-res; MPN ERJ2GE0R00X
R22, R31: R_3k01_0402; 0402-res; MPN CRCW04023K01FKED
R26: R_33k_0402; 0402-res; MPN RC0402FR-0733KL
R29, R30, R37: R_0R_0603; 0603-res; MPN CR0603-J/-000ELF
R33: R_12k_0402; 0402-res; MPN CRCW040212K0FKEDHP
R34: R_24k_0402; 0402-res; MPN ERJ2RKF2402X
R35: R_18k7_0402; 0402-res; MPN CR0402-FX-1872GLF
R36: R_15k_0402; 0402-res; MPN SFR01MZPF1502
TP1, TP2, TP3, TP4, TP5, TP6, TP7, TP8, TP9, TP10, TP11, TP12, TP23: TP_SMD_0_75MM; Testpoint_smd_0_75mm
U1: MP20073; MSOP-8-1EP_W3mm; MPN MP20073DH-LF-P
U2, U3: LM339; TSSOP-14_4.4x5mm_P0.65mm; MPN LM339PT
U4: DIO7553ST6; SOT23-6L; MPN DIO7553ST6
U5, U6, U7: AP62301WU-7; TSOT23-6; MPN AP62301WU-7
U8, U9, U10: AP7330-W5-7; SOT-23-5; MPN AP7330-W5-7

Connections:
1V0_Clean: C29.1, R29.2, TP5.1, U2.9 (+)
+1V2: C30.1, R30.2, TP8.1, U3.7 (+); also elsewhere on the board
+1V5: R5.1, R7.2, R42.2, TP7.1, U3.5 (+); also elsewhere on the board
+5V: C1.1, C2.1, C10.1, R2.2, R13.2, R14.2, R15.1, R16.1, R17.1, R18.2, TP2.1, U2.3 (V+), U3.3 (V+), U3.11 (+); also elsewhere on the board
/Power Supply/1V0_OUT: C20.1, C23.1, C26.1, C32.1, L1.2, R22.2, R41.1
/Power Supply/1V0_SW: C9.2, L1.1, U5.2 (SW)
/Power Supply/1V5_OUT: C21.1, C24.1, C27.1, C33.1, L2.2, R10.2, R42.1
/Power Supply/1V5_SW: C14.2, L2.1, U6.2 (SW)
/Power Supply/3V3_OUT: C22.1, C25.1, C28.1, C34.1, L3.2, R26.2, R40.1
/Power Supply/3V3_SW: C15.2, L3.1, U7.2 (SW)
/Power Supply/5V_1V0_IN: C11.1, R15.2, U5.3 (VIN)
/Power Supply/5V_1V5_IN: C12.1, R16.2, U6.3 (VIN)
/Power Supply/5V_3V3_IN: C13.1, R17.2, U7.3 (VIN)
/Power Supply/5V_I: Q2.1, Q3.2 (S), R13.1, U4.6 (OUT)
/Power Supply/FFC2_5V_1: C4.1, R4.2, R6.2, R63.2, U4.1 (IN)
/Power Supply/USB_POWER_IN: J1.A4 (VBUS), J1.A9 (VBUS), J1.B4 (VBUS), J1.B9 (VBUS), Q1.1 (G), Q2.4, Q3.3 (D), R9.2
/Power Supply/VREF_0V45: R2.1, R3.2, U2.4 (-), U2.6 (-), U2.8 (-), U2.10 (-), U3.4 (-), U3.6 (-), U3.8 (-)
/Power Supply/~FAULT: R6.1, TP23.1, U4.4 (~FAULT)
FFC2_5V: R4.1; also elsewhere on the board
unnamed: C3.2, R7.1, U1.6 (REF)
unnamed: C5.1, R5.2, U1.1 (DDQ)
unnamed: C9.1, U5.6 (BST)
unnamed: C14.1, U6.6 (BST)
unnamed: C15.1, U7.6 (BST)
unnamed: D1.1, R14.1, U2.1, U2.2, U2.13, U2.14, U3.1, U3.2, U3.14
unnamed: D2.1, R18.1
unnamed: J1.A5 (CC1), R11.2
unnamed: J1.B5 (CC2), R8.2
unnamed: Q1.3 (D), R63.1, U4.3 (EN)
unnamed: Q2.2, Q2.3, Q2.5, R64.2
unnamed: Q2.6, Q3.1 (G), R99.2
unnamed: R1.1, U1.7 (VttEN)
unnamed: R10.1, R12.1, U6.4 (FB)
unnamed: R19.2, R24.1, U8.1 (Vin)
unnamed: R20.2, R25.1, U9.1 (Vin)
unnamed: R21.2, R28.1, U10.1 (Vin)
unnamed: R22.1, R23.2, U5.4 (FB)
unnamed: R24.2, U8.3 (EN)
unnamed: R25.2, U9.3 (EN)
unnamed: R26.1, R27.2, U7.4 (FB)
unnamed: R28.2, U10.3 (EN)
unnamed: R30.1, R33.2, U9.5 (Vout)
unnamed: R31.1, R32.2, U8.4 (ADJ)
unnamed: R29.1, R31.2, U8.5 (Vout)
unnamed: R33.1, R34.2, U9.4 (ADJ)
unnamed: R35.1, R36.2, U10.4 (ADJ)
unnamed: R35.2, R37.1, U10.5 (Vout)
unnamed: R98.2, U4.5 (ILIM)
unnamed: TP10.1, U5.5 (EN)
unnamed: TP11.1, U6.5 (EN)
unnamed: TP12.1, U7.5 (EN)
Vref: C6.2, U1.8 (VttREF); also elsewhere on the board
Vtt: C7.1, C8.1, U1.2 (Vtt), U1.4 (VttSEN), U3.9 (+); also elsewhere on the board

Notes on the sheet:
DDR MEMORY TERMINATION SUPPLY
300mA max
INTERNAL POWER
LDOs
Ideal diode
2.0A max 86% eff 11mV est. ripple
Nominal currents are lower than rated
2.0A max 93% eff 26mV est. ripple
Sense
SUPPLY SELECTION
Open collector outputs pull down when no voltage on one of the rails
CONVERTERS
5V POWER
USB-C takes precedence over power via FFC
PS BLOCK DIAGRAM
TEST POINTS
2.0A max 86% eff 10mV est. ripple
POWER INDICATORS

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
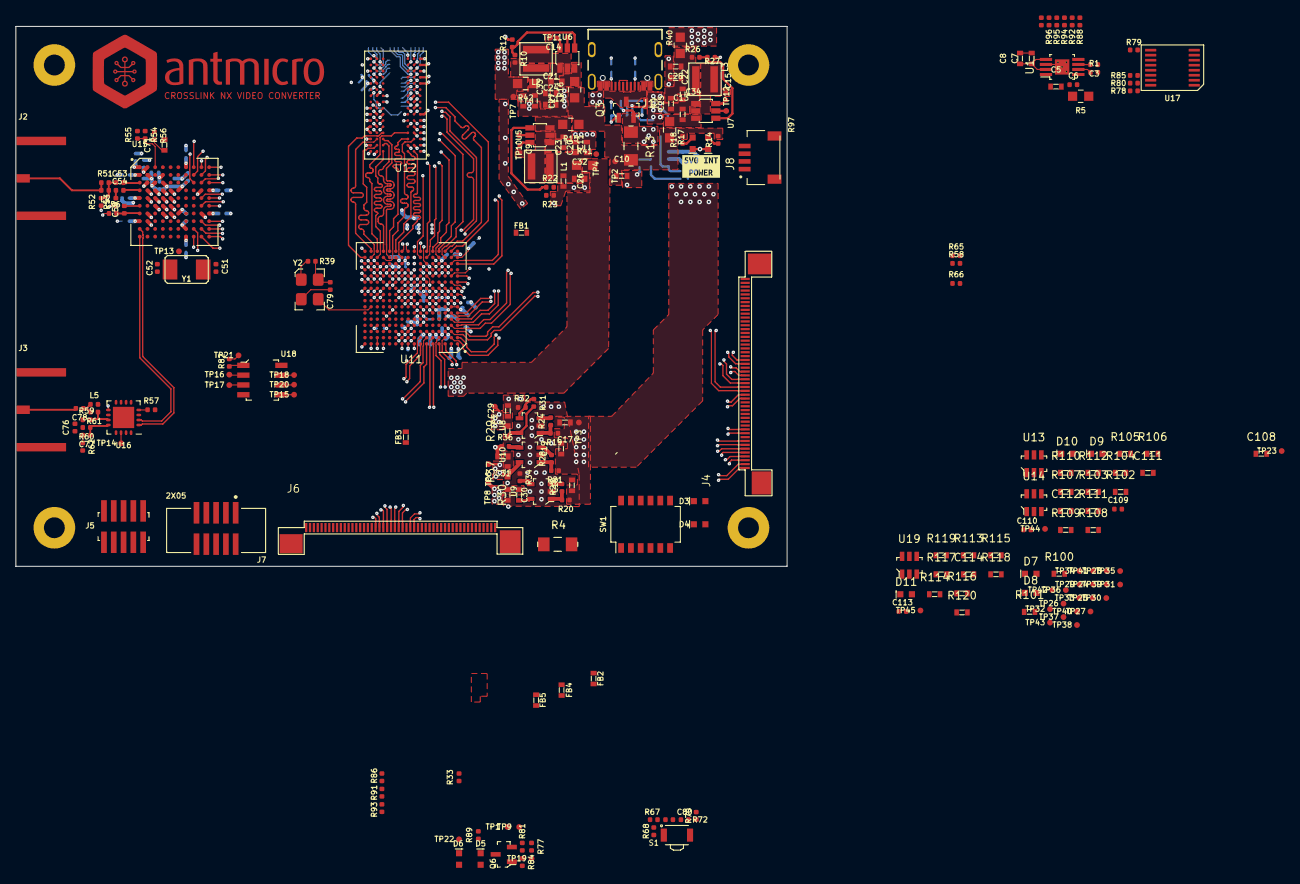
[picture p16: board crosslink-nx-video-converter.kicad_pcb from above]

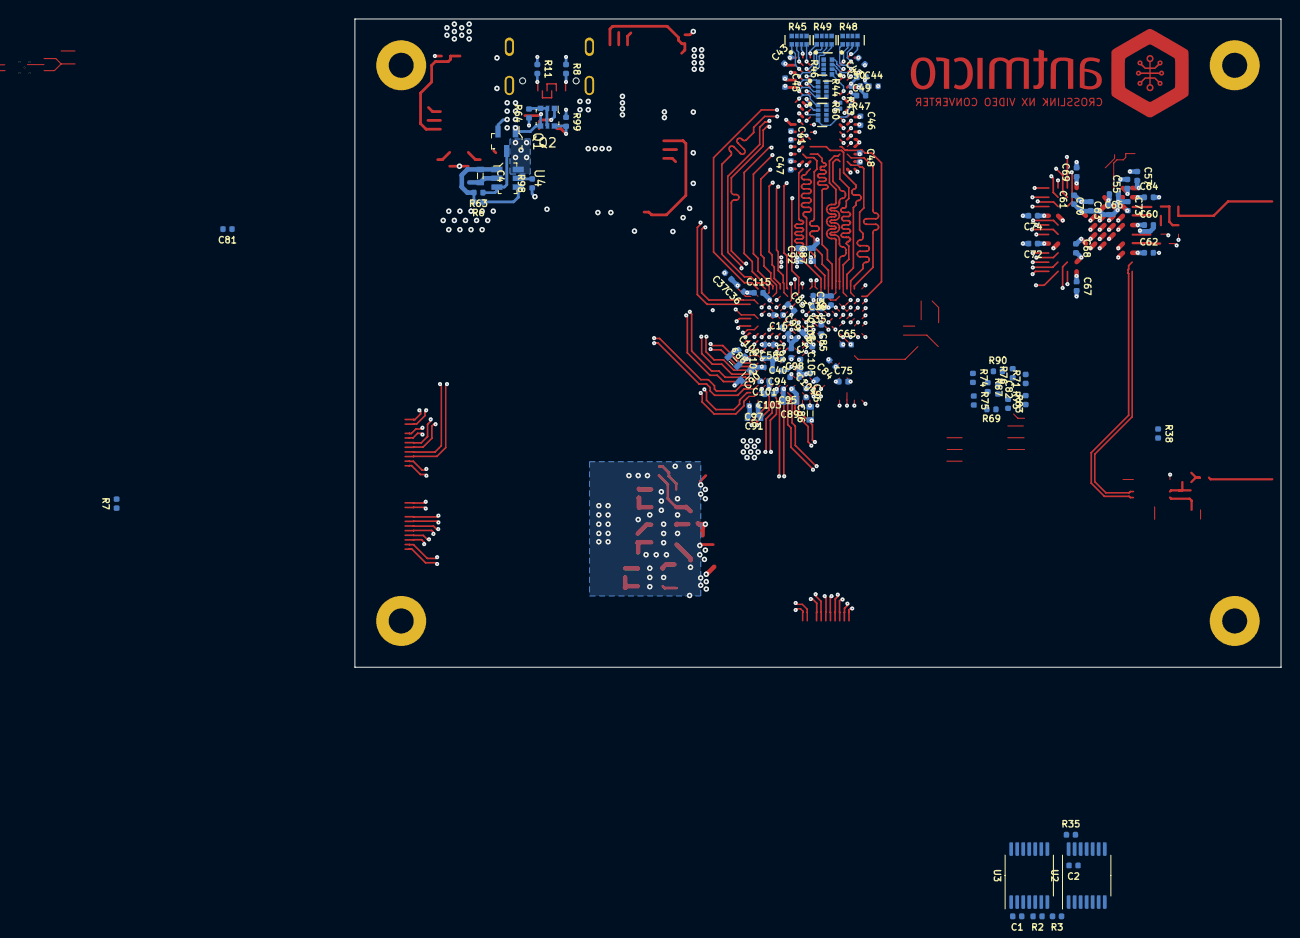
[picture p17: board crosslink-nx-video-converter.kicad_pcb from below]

Board: 8 copper layers, 100.0 x 70.0 mm, 337 parts (100 on the bottom side), 302 nets.

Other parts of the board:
R73, R74: R_0R_0402; 0402-res
kibuzzard-62FF6425: G***; kibuzzard-62FF6425

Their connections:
/FPGA/SPI_DQ2: R73.1; also elsewhere on the board
/FPGA/SPI_DQ3: R74.2; also elsewhere on the board

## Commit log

2022-07-06 Added 3.3V and 1V0_Power SMPSs
    [crosslink-nx-video-converter.kicad_sch]
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2022-07-06 Redesigned 3.3V supply taking into the consideration reduced power requirements
    [crosslink-nx-video-converter.kicad_sch, supply.kicad_sch]
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2022-11-25 Completed schematic of MT41K128M16JT memory module
    [crosslink-nx-video-converter.kicad_sch, ddr3.kicad_sch, supply.kicad_sch]
2022-11-25 Recalculated PSU SMPSs ratings
    [supply.kicad_sch]
2022-11-25 Fixed differential pair names
    [ddr3.kicad_sch]
2022-11-25 Added DDR3 Vtt and Vref regulator
    [crosslink-nx-video-converter.kicad_pcb, crosslink-nx-video-converter.kicad_sch, ddr3.kicad_sch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]
2022-11-25 Fixed VREF connection
    [crosslink-nx-video-converter.kicad_sch, ddr3.kicad_sch, supply.kicad_sch]
2022-11-25 Made a connection between DDR3 and fpga on the schematic
    [crosslink-nx-video-converter.kicad_sch, ddr3.kicad_sch, fpga.kicad_sch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]
2022-11-25 Fixed net labels
    [crosslink-nx-video-converter.kicad_sch, ddr3.kicad_sch, fpga.kicad_sch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]
2022-11-25 Connected soft MIPI CSI to FPGA
    [crosslink-nx-video-converter.kicad_sch, ddr3.kicad_sch, fpga.kicad_sch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]
2022-11-25 Connected FPGA to power supply and added power filtering
    [crosslink-nx-video-converter.kicad_pcb, crosslink-nx-video-converter.kicad_sch, fpga.kicad_sch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]
2022-11-25 Connected EN pins on PSU schematic
    [crosslink-nx-video-converter.kicad_pcb, crosslink-nx-video-converter.kicad_sch, fpga.kicad_sch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]
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2022-11-25 Added input and output termination
    [sdi.kicad_sch]
2022-11-25 Connected Semtech to the power supply, cable driver and the FPGA
    [crosslink-nx-video-converter.kicad_pcb, crosslink-nx-video-converter.kicad_sch, fpga.kicad_sch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]
2022-11-25 Added FPGA configuration circuitry
    [FPGA_Power.kicad_sch, crosslink-nx-video-converter.kicad_sch, fpga.kicad_sch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]
2022-11-25 Replaced RPi camera connector with 50pin one, modified PSU with ability of being supplied via FFC
    [crosslink-nx-video-converter.kicad_sch, fpga.kicad_sch, peripherals.kicad_sch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]
2022-11-25 Added indicator LEDs and user switch
    [crosslink-nx-video-converter.kicad_sch, fpga.kicad_sch, peripherals.kicad_sch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]
2022-11-25 Added optional oscillator
    [crosslink-nx-video-converter.kicad_sch, fpga.kicad_sch, peripherals.kicad_sch]
2022-11-25 Small fix to power switch circuitry
    [crosslink-nx-video-converter.kicad_sch, supply.kicad_sch]
2022-11-25 Small I2C connection fix
    [fpga.kicad_sch]
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2022-11-25 Removed components outside PCB
    [crosslink-nx-video-converter.kicad_pcb]
2022-11-25 Divided FPGA into multiple blocks
    [FPGA_Power.kicad_sch, crosslink-nx-video-converter.kicad_sch, ddr3.kicad_sch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]
2022-11-25 Modified power indicator and connected unused pins
    [FPGA_Power.kicad_sch, crosslink-nx-video-converter.kicad_pcb, crosslink-nx-video-converter.kicad_sch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]
2022-11-25 Added updated block diagram
    [crosslink-nx-video-converter.kicad_sch, fpga.kicad_sch]
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2022-11-25 Switched voltages to support DDR3 and RPC memories
    [crosslink-nx-video-converter.kicad_sch, ddr3.kicad_sch, fpga.kicad_sch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]
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2022-11-25 Routed SDI data interface
    [crosslink-nx-video-converter.kicad_pcb, sdi.kicad_sch]
2022-11-25 Rerouted some DDR3 signals
    [crosslink-nx-video-converter.kicad_pcb, ddr3.kicad_sch]
2022-11-25 Fixed SDI top impedance
    [crosslink-nx-video-converter.kicad_pcb]
2022-11-25 Length matched most high speed interfaces
    [crosslink-nx-video-converter.kicad_pcb, crosslink-nx-video-converter.kicad_sch, sdi.kicad_sch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]
2022-11-25 Small fixes to high speed signals
    [crosslink-nx-video-converter.kicad_pcb]
2022-11-25 Changed DC jack to USB-C, added power switch for FFC1, fixed MP20073
    [crosslink-nx-video-converter.kicad_sch, peripherals.kicad_sch, supply.kicad_sch]
2022-11-25 Added testpoints and LEDs for SDI circuitry
    [crosslink-nx-video-converter.kicad_sch, sdi.kicad_sch]
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2022-11-25 Fixed via size, changed connector placement
    [crosslink-nx-video-converter.kicad_pcb]
2022-11-25 Small clearence fix
    [crosslink-nx-video-converter.kicad_pcb]
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2022-11-25 Started power supply layoyt
    [crosslink-nx-video-converter.kicad_pcb, crosslink-nx-video-converter.kicad_sch, supply.kicad_sch]
2022-11-25 Completed the layout of the PSU
    [crosslink-nx-video-converter.kicad_pcb, crosslink-nx-video-converter.kicad_sch, supply.kicad_sch]
2022-11-25 Power planes initial layout
    [crosslink-nx-video-converter.kicad_pcb]
2022-11-25 Fix FPGA power supply
    [FPGA_Power.kicad_sch, crosslink-nx-video-converter.kicad_sch]
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2022-11-25 Routed rest of low speed signals
    [crosslink-nx-video-converter.kicad_sch, ddr3.kicad_sch, sdi.kicad_sch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]
2022-11-25 Fixed few DRC issues, replaced one power trace with zone
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2022-11-25 Fixed component silkscreen
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2022-11-25 Added DRC rules and fixed track width/gap width/length matching issues
2022-11-25 Added 0R to low speed FFC signals, moved few testpoints
    [FPGA_Power.kicad_sch, crosslink-nx-video-converter.kicad_sch, peripherals.kicad_sch]
2022-11-25 Added optional header connector for GPIO
    [crosslink-nx-video-converter.kicad_sch, peripherals.kicad_sch]
2022-11-25 Added FT230XQ-R for USB connectivity
    [crosslink-nx-video-converter.kicad_sch, fpga.kicad_sch, peripherals.kicad_sch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]
2022-11-25 Added USB power cap, fixed USB routing, moved gpio header connector back
    [crosslink-nx-video-converter.kicad_sch, peripherals.kicad_sch]
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2022-11-25 Added revision and title to the schematic sheets
    [FPGA_Power.kicad_sch, crosslink-nx-video-converter.kicad_sch, ddr3.kicad_sch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]
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2022-11-30 Update PCB routing
    - apply new DRC
    - add FPGA package delay to the high speed traces tunning
    - improve GND and power planes
    [FPGA_Power.kicad_sch, crosslink-nx-video-converter.kicad_sch, ddr3.kicad_sch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]
2022-12-12 Update project naming convention
    [FPGA_Power.kicad_sch, crosslink-nx-video-converter.kicad_sch, ddr3.kicad_sch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]
2022-12-12 Bump to 1.1.0, update naming
    [FPGA_Power.kicad_sch, ddr3.kicad_sch, fpga.kicad_sch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]
2022-12-12 Update U11/LIFCL-40-9BG256C footprint property
    [FPGA_Power.kicad_sch, ddr3.kicad_sch, fpga.kicad_sch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]
2022-12-12 Add logotypes to schematics
    [FPGA_Power.kicad_sch, ddr3.kicad_sch, fpga.kicad_sch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]
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2023-01-03 Fixed mirrored vtt regulator component
    [FPGA_Power.kicad_sch, ddr3.kicad_sch, fpga.kicad_sch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]
2023-01-30 Added mux on SPI
    [fpga.kicad_sch, peripherals.kicad_sch, sdi-mipi-video-converter.kicad_sch]
2023-01-30 Added SPI mux to layout
    [fpga.kicad_sch, sdi-mipi-video-converter.kicad_sch]
2023-01-30 Revision bumped to 1.1.2
    [FPGA_Power.kicad_sch, ddr3.kicad_sch, fpga.kicad_sch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]
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2023-10-12 Resolve ERC
    [FPGA_Power.kicad_sch, ddr3.kicad_sch, fpga.kicad_sch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]
2023-10-12 Cleanup silks overlapping other graphical items
    [fpga.kicad_sch, sdi.kicad_sch]
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2023-10-12 [#48149] Change LIFCL footprint for footprint with markings
    [FPGA_Power.kicad_sch, ddr3.kicad_sch, fpga.kicad_sch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]
2023-10-12 [#48149] Update GS297 and LIFCL symbols, update local lib
    [FPGA_Power.kicad_sch, ddr3.kicad_sch, fpga.kicad_sch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]
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2024-02-23 [#55653] Fix LIFCL-40
    [FPGA_Power.kicad_sch, ddr3.kicad_sch, fpga.kicad_sch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]
2024-02-26 [#55653] Fix manufacturer of LIFCL-40
    [FPGA_Power.kicad_sch, ddr3.kicad_sch, fpga.kicad_sch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]
2024-04-02 Fix symbols/footprint coordinates
    [FPGA_Power.kicad_sch, ddr3.kicad_sch, fpga.kicad_sch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]
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2025-11-03 Correct components
    [fpga.kicad_sch]
